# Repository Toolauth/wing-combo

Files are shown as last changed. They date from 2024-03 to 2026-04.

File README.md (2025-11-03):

# Combined Use Board
This is the **flagship board** for the [Toolauth](https://github.com/Toolauth) project.  More information about use, setup, and firmware is available in [this repo's wiki](https://github.com/Toolauth/wing-combo/wiki).

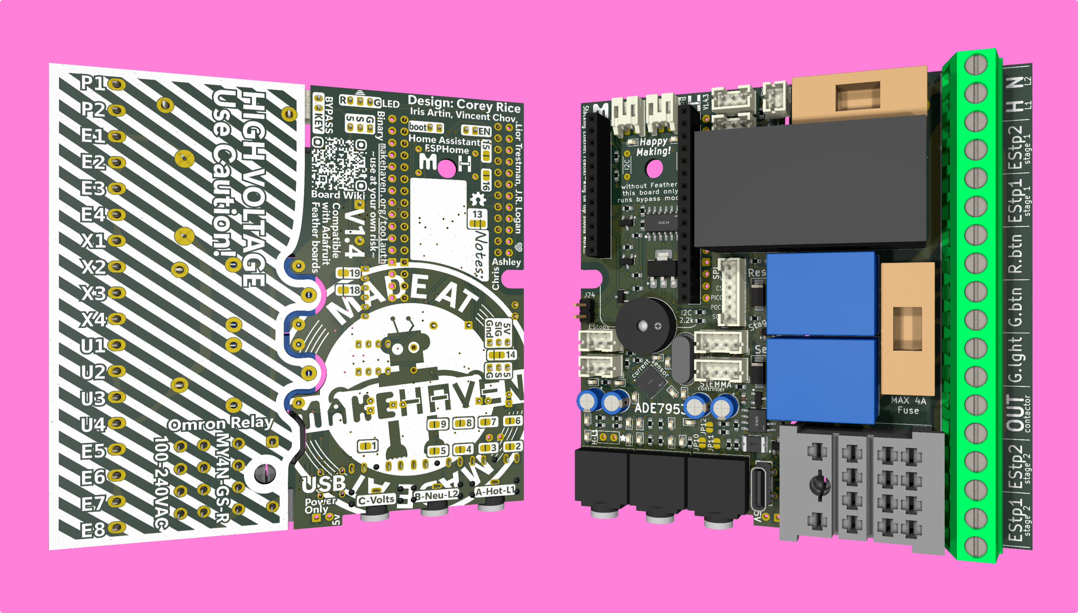
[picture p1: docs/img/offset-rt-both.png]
Combined use circuit board, front and back


It can allow for the management of power tools, and serve as the gateway for user authorization in a shared workshop.

The board has the following features:
* A stack of relays & a contactor for controlling power to the downstream tool.
* Its own power supply, to draw from the line supplying the downstream tool (_no extra power needed, if under 220VAC_).
* An ADE7953 current sensor, to monitor energy use/ status of the connected tool.
* Connectors to add in an RFID card reader (_workshop member's badges can swipe_).
* Connections for a hardware bypass, for quick-enabling of the tool.
* Simple connection for panel-mounted Red & Green status LEDs.
* 5V supply (from onboard transformer) in USB and solder-able form, for future expansion.

## How do I play with this PCB design?
It is as easy as downloading this design by whatever means you like: zip file, `clone`, etc. Then, open the `wing-combo.kicad_pro` file with any version of [KiCAD](https://www.kicad.org/) you like, but the newest version will probably be best.

## Adafuit Feather Specification
In avoidance of obsolescence, we have designed this board to the [Adafruit](https://www.adafruit.com/)'s [Feather Specification](https://learn.adafruit.com/adafruit-feather/feather-specification). The logic here is that the Feather specification itself should allow us to upgrade the 'brain' of this wing without needing a major re-design. 

_Yes, we could have designed a specific ESP32 into the board. But experience with previous generations has taught us that it is more convenient to make the boards with a MAC address removable._

## IOT Hosting
This project was designed to work with [Home Assistant](https://www.home-assistant.io/) and [ESPHome](https://esphome.io/), because they allow us to host the whole solution on-premises. However, this board is not tied to that stack by any means. There are lots of ways firmware and software could come together to make this work.

## Design Software
* Schematic and board designed in [KiCAD](https://www.kicad.org/).
* Graphics designed in [Inkscape](https://inkscape.org/).
* Ordered as assembled boards from [JLCPCB](https://jlcpcb.com/).

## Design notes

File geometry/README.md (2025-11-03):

# /geometry
All special geometry for this project is done in [Inkscape](https://inkscape.org/) and is derived from geometry exported from the board design in [KiCAD](https://www.kicad.org/). 

## file naming conventions
Files that end in `*.b141.svg` (or any board number) are primary Inkscape design files, and have carefully named layers, groups and drive all of the other designs.

Files that end in `*.multilayer.svg` all have multiple layers that represent the overlapping geometry of the board design. These files are useful for alignment and coordinating shapes with components on the board.

Files that end in `*.flattened.svg` are derived from their multilayer siblings, but have been reduced to just a single path that holds the information needed to import back into the KiCAD board design.

Files that end in `*.original_logo.svg` are primary-resource design files for the MakeHaven branding on the board.

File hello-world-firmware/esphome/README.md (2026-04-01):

# /esphome-hello-world
Here lives the simplest firmware examples, for use with ESPHome. 

They ought to connect all the standard/expected components, so that their state can be observed in [Home Assistant](https://www.home-assistant.io/) and [ESPHome](https://esphome.io/).

Here is the firmware that works.   
This was IRL tested with an [Adafruit Feather ESP32-S3 NoPSRAM](https://www.adafruit.com/product/5323) ([on platformio](https://docs.platformio.org/en/latest/boards/espressif32/adafruit_feather_esp32s3_nopsram.html))  

→ It appears the other [Feather Boards](https://learn.adafruit.com/adafruit-feather/feather-specification) have the same footprint, and all the “services” like `I2C` and `SPI` are in the same physical places. But the GPIO pin number can drift around from board to board: that is why this demo has GPIO you can commant/uncomment as needed. Also, to work in ESPHome, the board has to be supported by [Platformio](https://docs.platformio.org/en/latest/boards/)

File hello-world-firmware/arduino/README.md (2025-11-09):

# Example Arduino Firmware

> [!TIP]
> Arduino is not the firmware used by the [*Toolauth* project](https://github.com/Toolauth) creators.
> So, this firmware underwent less testing than the [ESPHome version](../esphome/). 
> Also, we recently had it 'touched up' by A.I. so you can use with caution....

This Arduino firmware is enough to show that all the hardware I/O is working for the board.

The Arduino IDE has opinions about libraries, so we have included a snapshot of all the needed ones and URLs to their origin. Open the folder, and have the Arduino IDE open the `io_test.ino` file to get this working on your board.

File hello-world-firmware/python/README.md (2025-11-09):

# Example Python Firmware

> [!CAUTION]
> We've never used this IO test - we just asked an A.I. to write it from the ESPHome version.

This Python firmware is enough to show that all the hardware I/O is working for the board.
You can get the microcontroller running as a webserver, and test that things work.

--> The tricky part will be finding the IP address of the board on your network...

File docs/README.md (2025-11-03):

# /docs
Here are all the basic documentation items:
* diagrams
* images
* layouts
* configurations

These items should help with setup

## Image Naming conventions
The images will all use a standard naming convention, so as to not break links on the wiki or Toolauth site. If you need to generate new images for a new design, be sure to use the same exact names. Also, the `map-locations.svg` file may be helpful.

- `docs\img\map\location-*.png` are images that show where specific parts are located on the board.
    - NOTE: in the `docs\img\map\` repo, there is an SVG file: `map-locations.svg` with many layers to generate the "location" images using [Inkscape](https://inkscape.org/). 
- `docs\img\map\sq-*.png` are the square(ish) images that serve as the foundation for all the location images, and generally take up less screen-area. Cropped down to size from "ortho" images using [Gimp](https://www.gimp.org/).
- `docs\img\map\ortho-*.png` are the orthographic perspective "base" images, from which all the square and location images are derived. Exported from [FreeCAD](https://www.freecad.org/) extension of [KiCAD](https://www.kicad.org/) (accessible from the `alt + 3` command).
- `docs\img\offset-*.png` are the "hero" images that use perspective (which blocks some viewing) and look the most realistic.

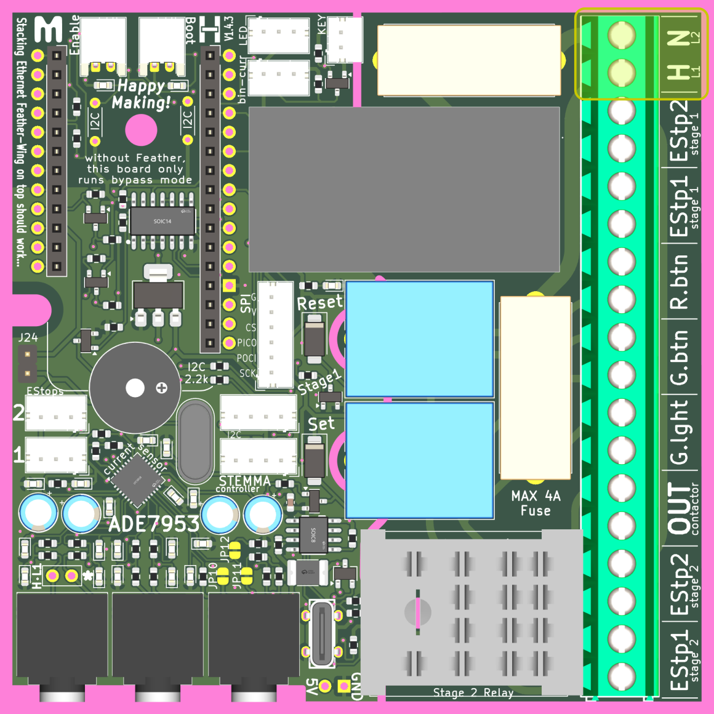
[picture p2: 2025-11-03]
docs/img/map/location-mains.png

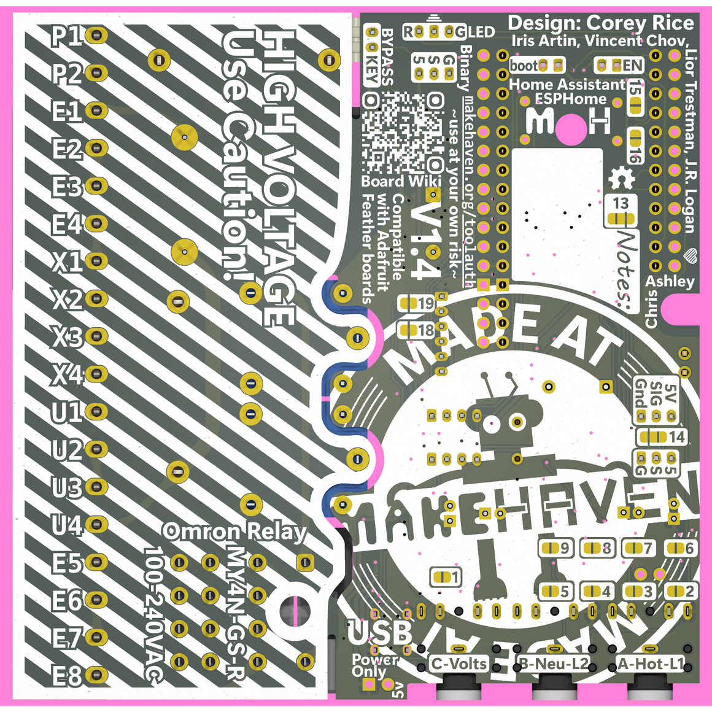
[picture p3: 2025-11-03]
docs/img/map/sq-ortho-back-rt.png

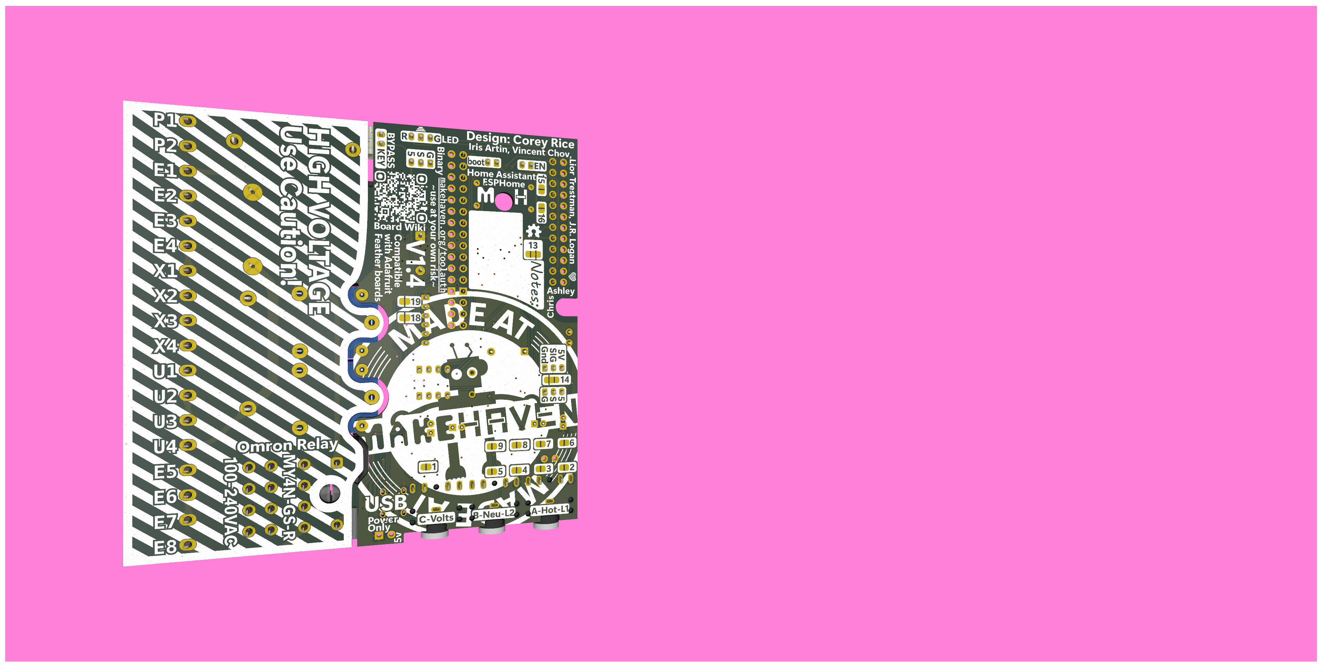
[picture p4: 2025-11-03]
docs/img/offset-rt-back.png

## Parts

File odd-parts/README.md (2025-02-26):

# /odd-parts
Here are all the components that are needed for the board design, but are not in the standard KiCAD library.

Include as much information as possible about these parts, so that they can be easily used, updated, researched, etc.

*****

The best tool to get this information is [JLC2KiCad_lib](https://github.com/TousstNicolas/JLC2KiCad_lib): a python script that gets all the files for a part from JLCPCB, and can store them here. 

example usage (make `some_accurate_name` a meaningful thing for this part):
```
JLC2KiCadLib C24112 -dir some_accurate_name                \
                    -model_dir some_accurate_name\model    \
                    -footprint_lib some_accurate_name      \
                    -symbol_lib_dir some_accurate_name\lib \
                    -symbol_lib some_accurate_name
```
Just need the part number as a positional argument. 

For our purposes, it is probably best if you stick to these conventions: each odd-part gets its own folder inside this one, and its own self-titled KiCad library.

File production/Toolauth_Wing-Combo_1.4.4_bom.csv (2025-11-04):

Designator | Footprint | Quantity | Value | LCSC Part #
BZ1 | BUZ-TH_BD12.0-P7.60-D0.6-FD | 1 | Buzzer | C96095
C1, C2, C24 | 0603 | 3 | 0.1uF | C14663
C10, C11, C12, C3, C4, C5, C6, C7, C8, C9 | 0603 | 10 | 33nF | C21117
C13, C16, C17, C22 | 0603 | 4 | 100nF | C14663
C14 | CP_Radial_D5.0mm_P2.00mm | 1 | 10uF | C88726
C15 | 0603 | 1 | 1uF | C15849
C18, C19, C23 | CP_Radial_D5.0mm_P2.00mm | 3 | 4.7uF | C88759
C20, C21 | 0603 | 2 | 20pF | C1648
D1 | 0603 | 1 | LED | C2286
D2, D3 | D_SMA | 2 | SS14 | C2480
F1 | Fuseholder_Cylinder-5x20mm_Stelvio-Kontek_PTF78_Horizontal_Open | 1 | Fuse | C717030
F2 | Fuseholder_Cylinder-5x20mm_Stelvio-Kontek_PTF78_Horizontal_Open | 1 | Fuse | C717030
F3 | 1812 | 1 | Polyfuse | C17313
J1 | PinSocket_1x12_P2.54mm_Vertical | 1 | Conn_01x12 | C2905419
J10 | JST_PH_B2B-PH-K_1x02_P2.00mm_Vertical | 1 | Conn_01x02_Female | C131337
J11, J12 | JST_PH_B4B-PH-K_1x04_P2.00mm_Vertical | 2 | Conn_01x04_Female | C131334
J13, J14, J15, J17 | JST_PH_B3B-PH-K_1x03_P2.00mm_Vertical | 4 | Conn_01x03_Female | C131339
J16 | JST_PH_B6B-PH-K_1x06_P2.00mm_Vertical | 1 | Conn_01x06_Female | C131342
J18, J19 | JST_PH_S2B-PH-K_1x02_P2.00mm_Horizontal | 2 | Conn_01x02_Female | C157932
J2 | PinSocket_1x16_P2.54mm_Vertical | 1 | Conn_01x16 | C2905421
J20, J21, J22 | CONN-TH_6P-P5.00_MX128-5.0-06P-GN01-CU-Y-A | 3 | Screw_Terminal_01x06 | C5290371
J24 | PinHeader_1x02_P2.54mm_Vertical | 1 | powered | C492401
J5, J6, J7 | Jack_3.5mm_CUI_SJ1-3525N_Horizontal | 3 |  | C692542
J8 | USB-C-TH_GT-USB-7055 | 1 | USB_C_Receptacle_USB2.0_16P | C2686963
JP1, JP15, JP16, JP2, JP3, JP4, JP5, JP6, JP7, JP8, JP9 | SolderJumper-2_P1.3mm_Open_RoundedPad1.0x1.5mm | 11 | no-filter-1
JP10, JP11, JP12, JP18, JP19 | SolderJumper-2_P1.3mm_Bridged_RoundedPad1.0x1.5mm | 5 | bridged
JP13, JP14 | SolderJumper-3_P1.3mm_Bridged12_RoundedPad1.0x1.5mm | 2 | SolderJumper_3_Bridged12
Q1 | TSOT-23 | 1 | PMOS | C15127
R1, R14, R15, R16, R17, R18, R20, R21, R26, R27, R29, R5, R6 | 0603 | 13 | 1k | C21190
R10, R11, R12, R9 | 0603 | 4 | 100 | C22775
R13, R19 | 0603 | 2 | 499k | C131054
R2, R22, R23, R24, R25, R28, R3, R30, R31, R36, R37, R38, R39, R4, R40 | 0603 | 15 | 10k | C25804
R34, R35 | 0603 | 2 | 56k | C23206
R7, R8 | 0603 | 2 | 2.2k | C4190
RELAY1, RELAY2 | Relay_SPDT_SANYOU_SRD_Series_Form_C | 2 | JQC-3FF/005-1ZS(551) | C9221
T1, T2, T3, T4, T5, T6 | SOT-23 | 6 | AO3400A | C427382
U1 | SOIC-14_L8.7-W3.9-P1.27-LS6.0-BL | 1 | 74HC02 | C350559
U2 | LFCSP-28-1EP_5x5mm_P0.5mm_EP3.14x3.14mm | 1 | ADE7953xCP | C515890
U3 | SOT-223-3_TabPin2 | 1 | AMS1117-3.3 | C6186
U4 | SOIC-8_L5.0-W4.0-P1.27-LS6.0-BL | 1 | LM393 | C7955
Y1 | Crystal_HC49-4H_Vertical | 1 | 3.58MHz | C2826865

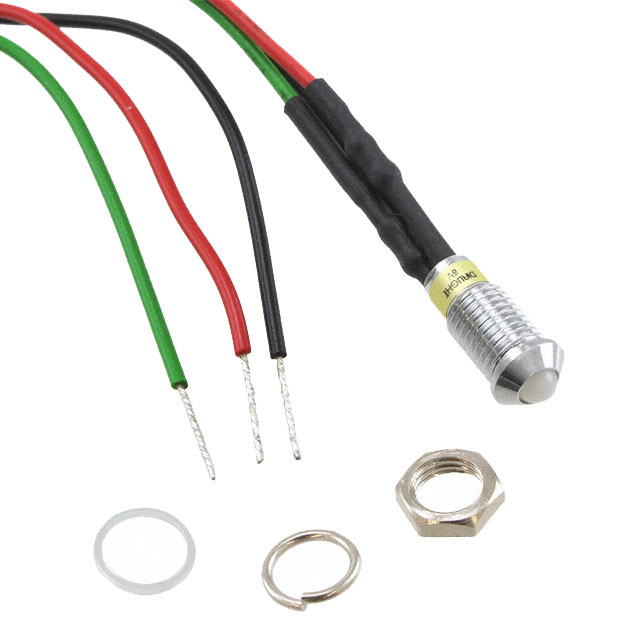
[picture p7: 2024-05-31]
docs/img/parts/led.jpg

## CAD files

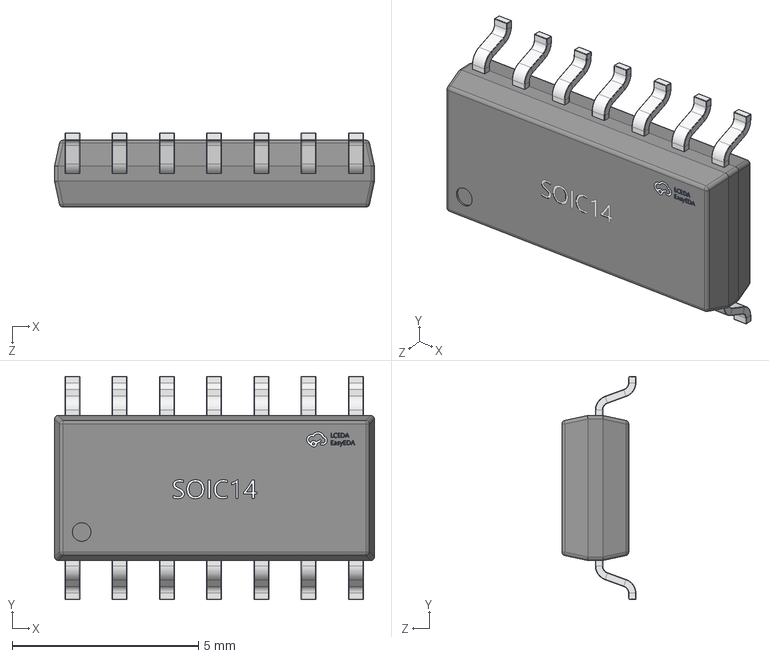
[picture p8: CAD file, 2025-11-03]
odd-parts/74hc02d/74hc02d_lib/model/SOIC-14_L8.7-W3.9-P1.27-LS6.0-BL.step
8.60 x 6.01 x 2.00 mm

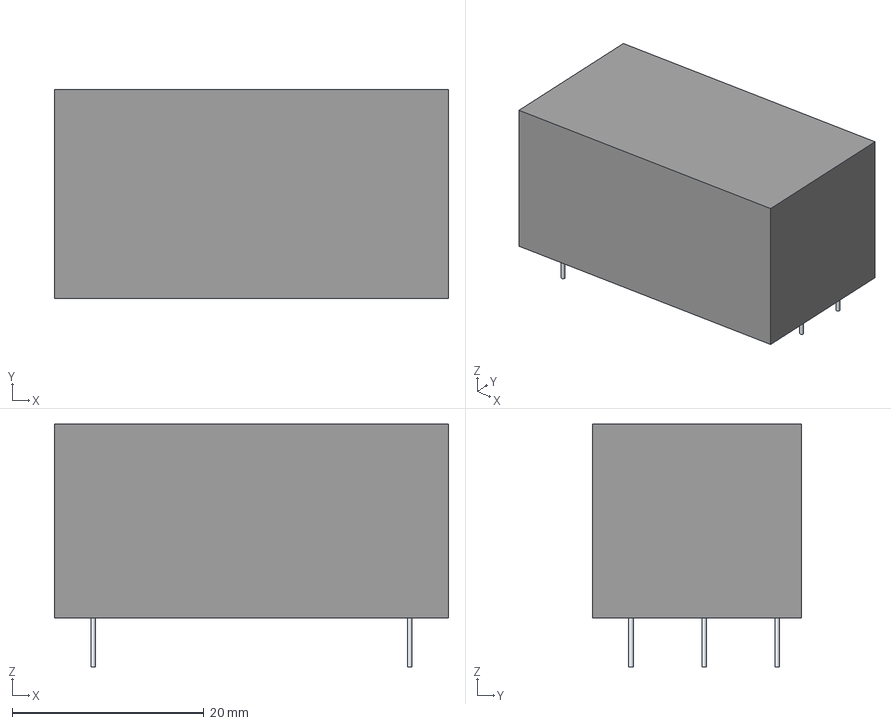
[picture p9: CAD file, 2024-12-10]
odd-parts/CFM06S050-E-Cincon/CFM06S050-E.stp
41.1 x 21.8 x 25.3 mm
Leads x 4

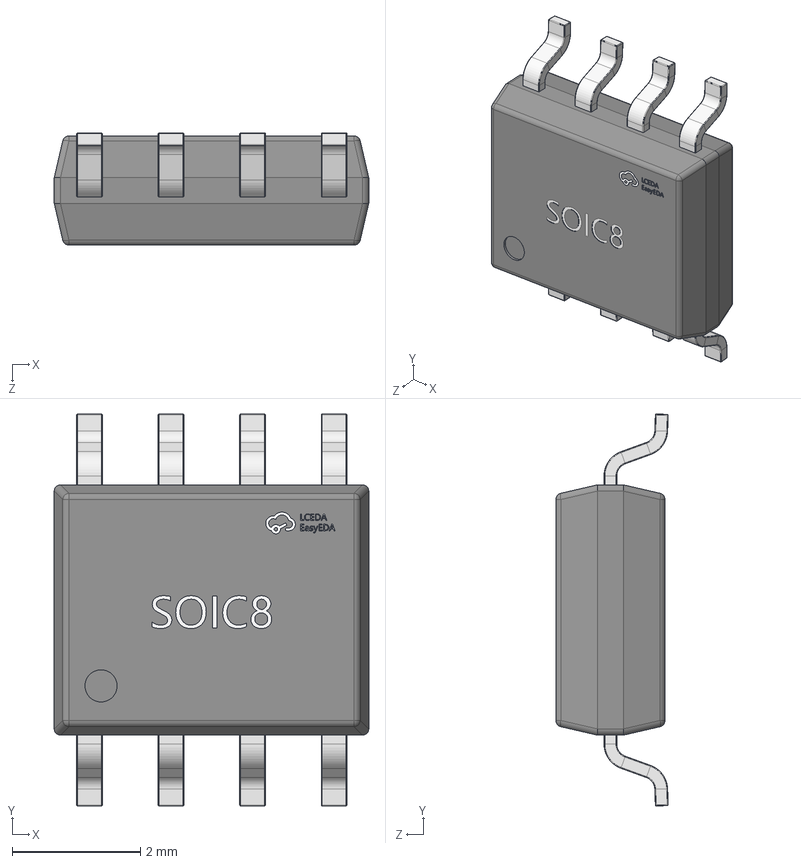
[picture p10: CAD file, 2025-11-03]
odd-parts/lm393/lm393/lm393model/SOIC-8_L5.0-W4.0-P1.27-LS6.0-BL.step
4.90 x 6.11 x 1.75 mm

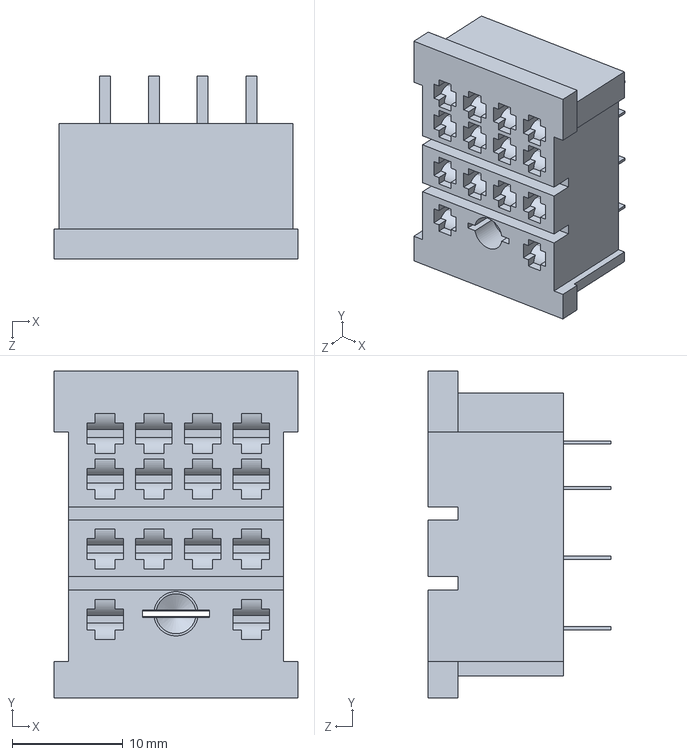
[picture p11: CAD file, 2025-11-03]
odd-parts/mk_relay_socket/PY14_02.step
22.0 x 29.5 x 16.5 mm

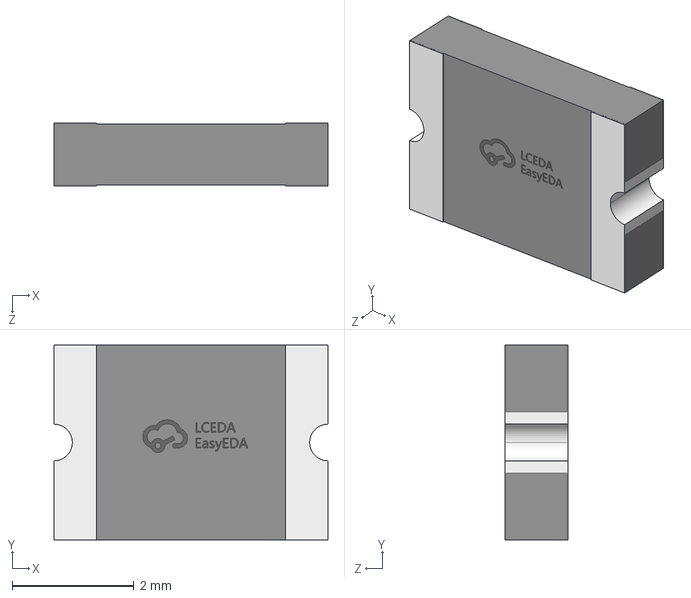
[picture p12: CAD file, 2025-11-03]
odd-parts/PPTC_fuse/PPTC_fuse/PPTC_fusemodel/F1812.step
4.50 x 3.20 x 1.04 mm

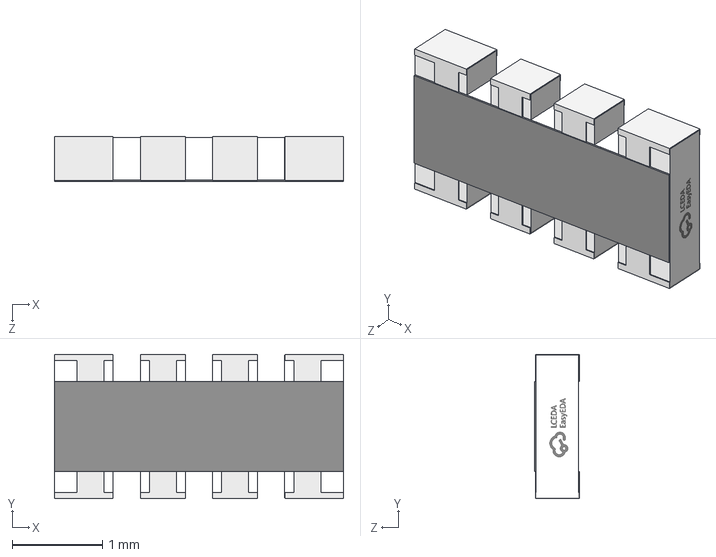
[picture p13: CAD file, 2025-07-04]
odd-parts/resistor_arrays/resistor_arrays/model/RES-ARRAY-SMD_0603-8P-L3.2-W1.6-BL.step
3.20 x 1.60 x 0.5 mm

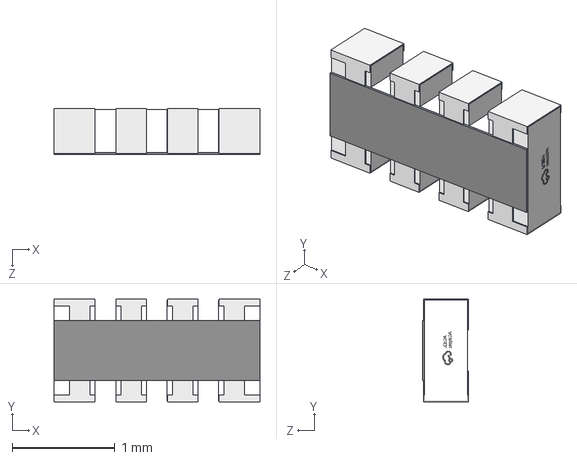
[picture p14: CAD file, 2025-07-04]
odd-parts/resistor_arrays/resistor_arrays/model/RES-ARRAY-SMD_0402-8P-L2.0-W1.0-BL.step
2.00 x 1.00 x 0.45 mm

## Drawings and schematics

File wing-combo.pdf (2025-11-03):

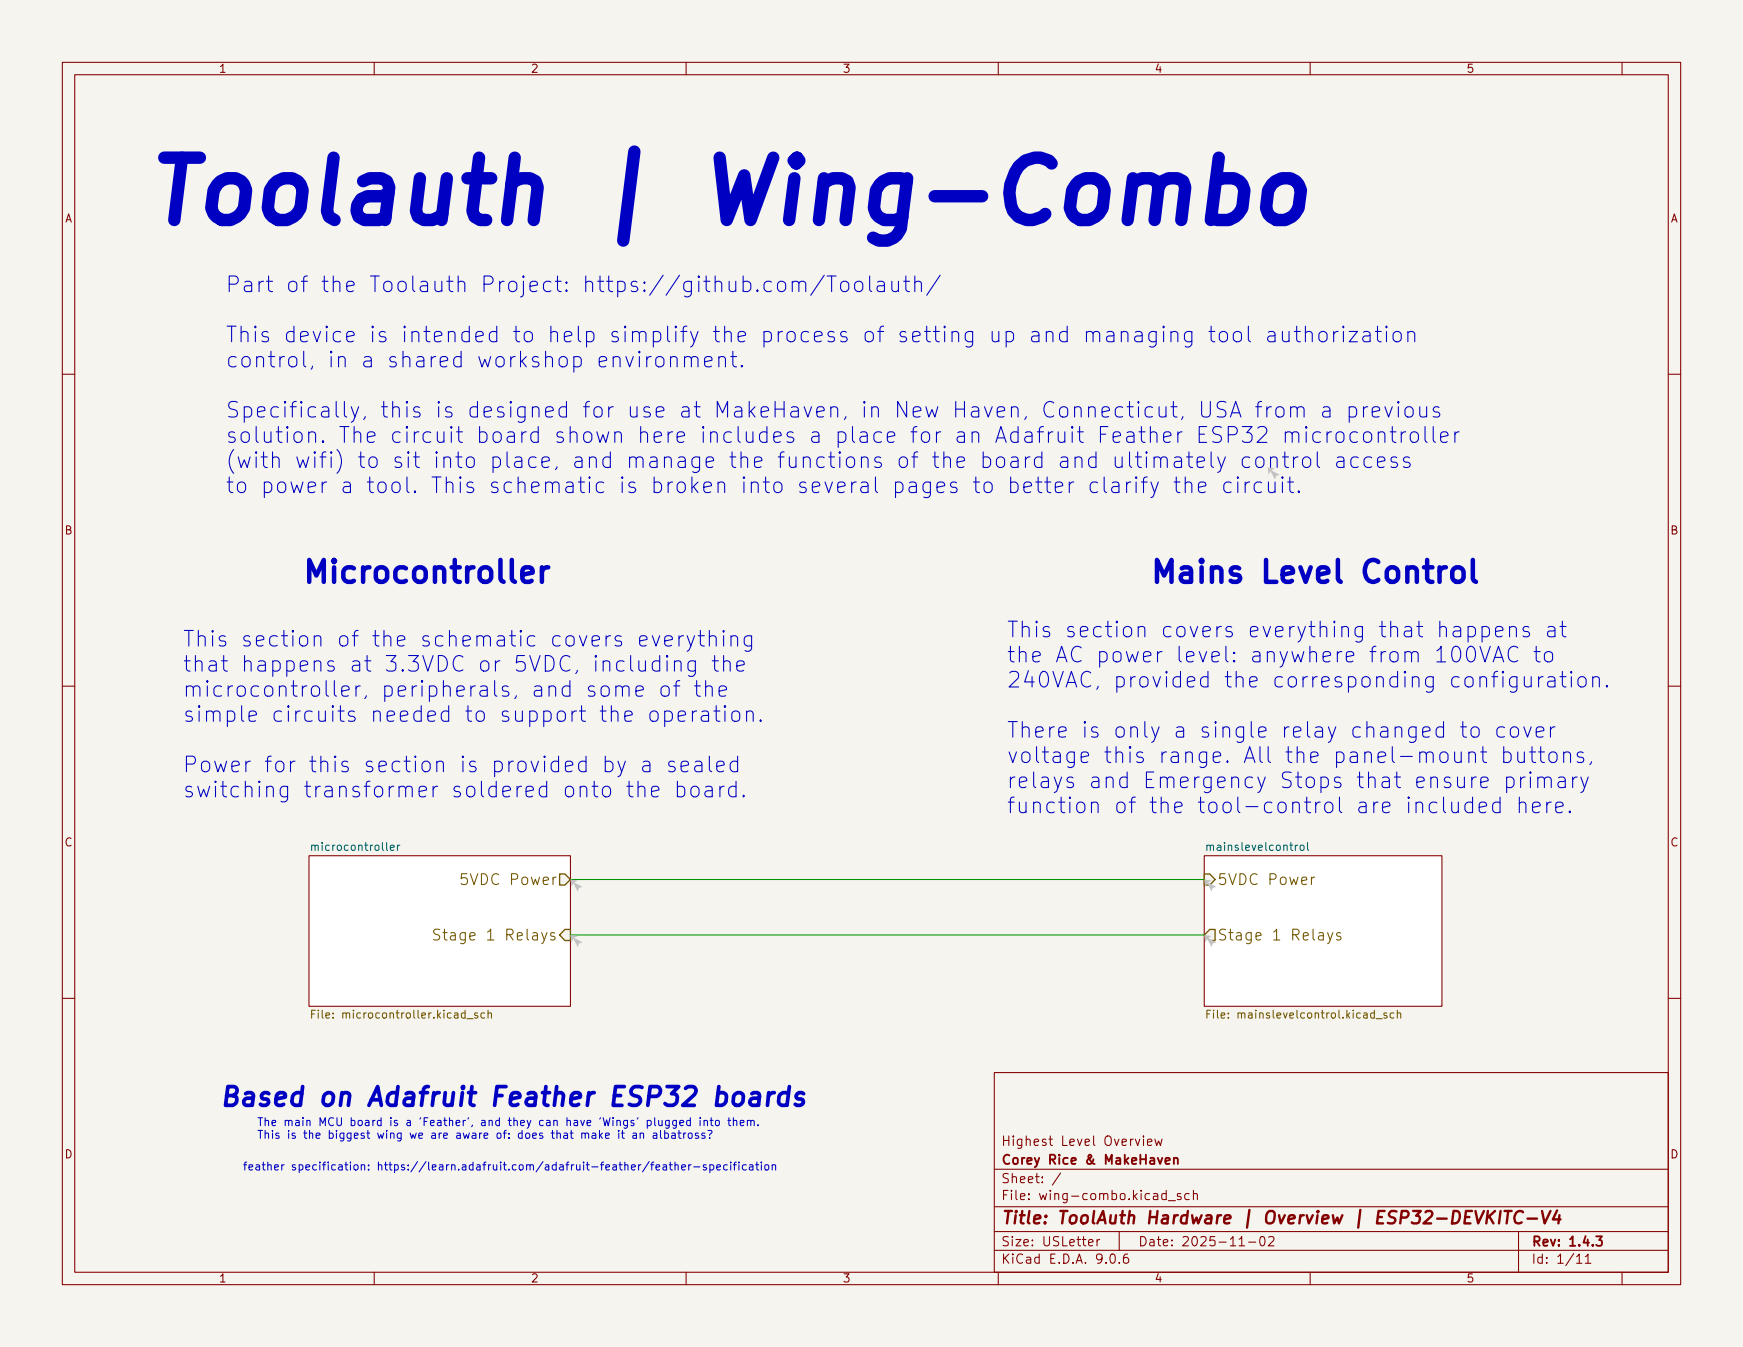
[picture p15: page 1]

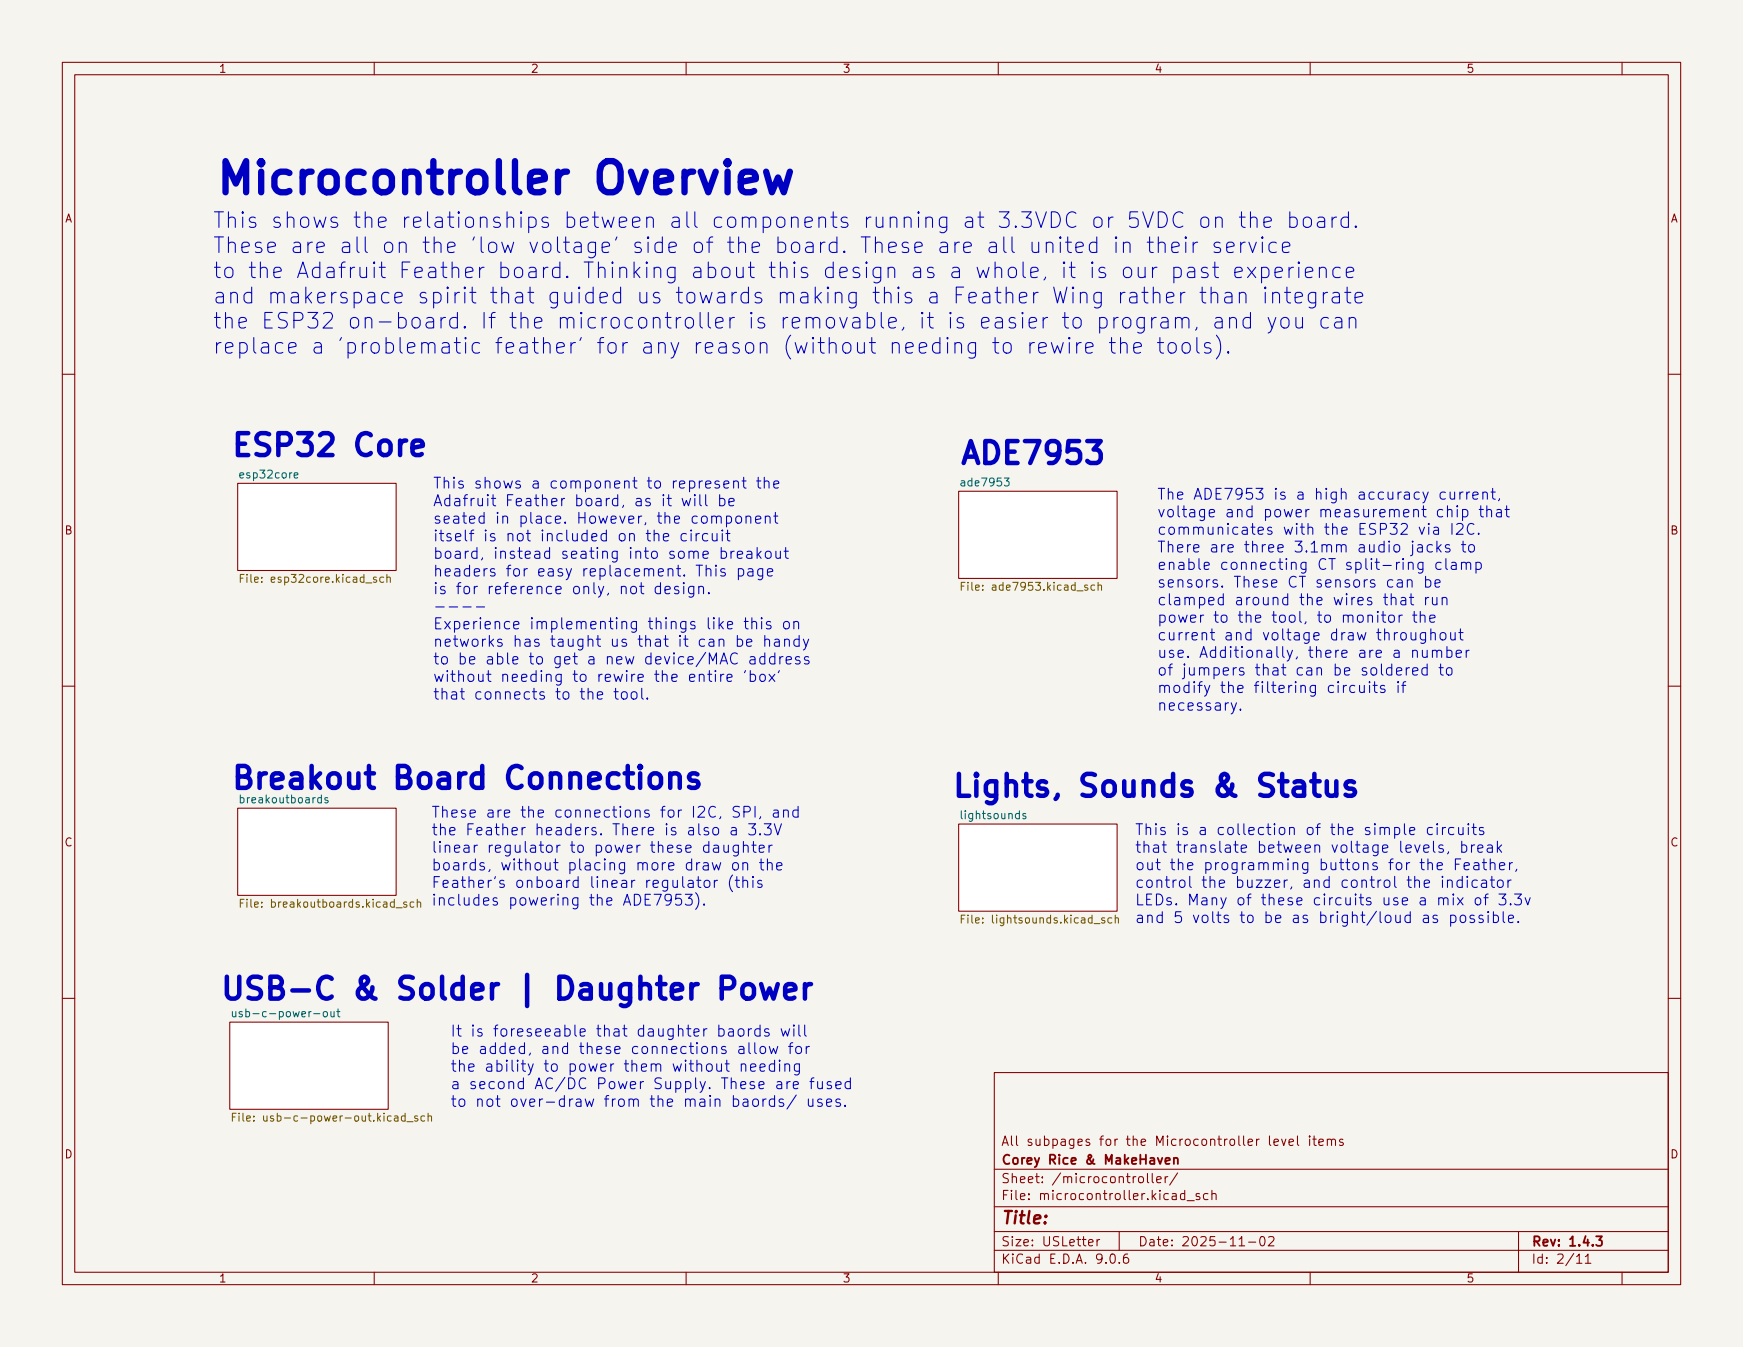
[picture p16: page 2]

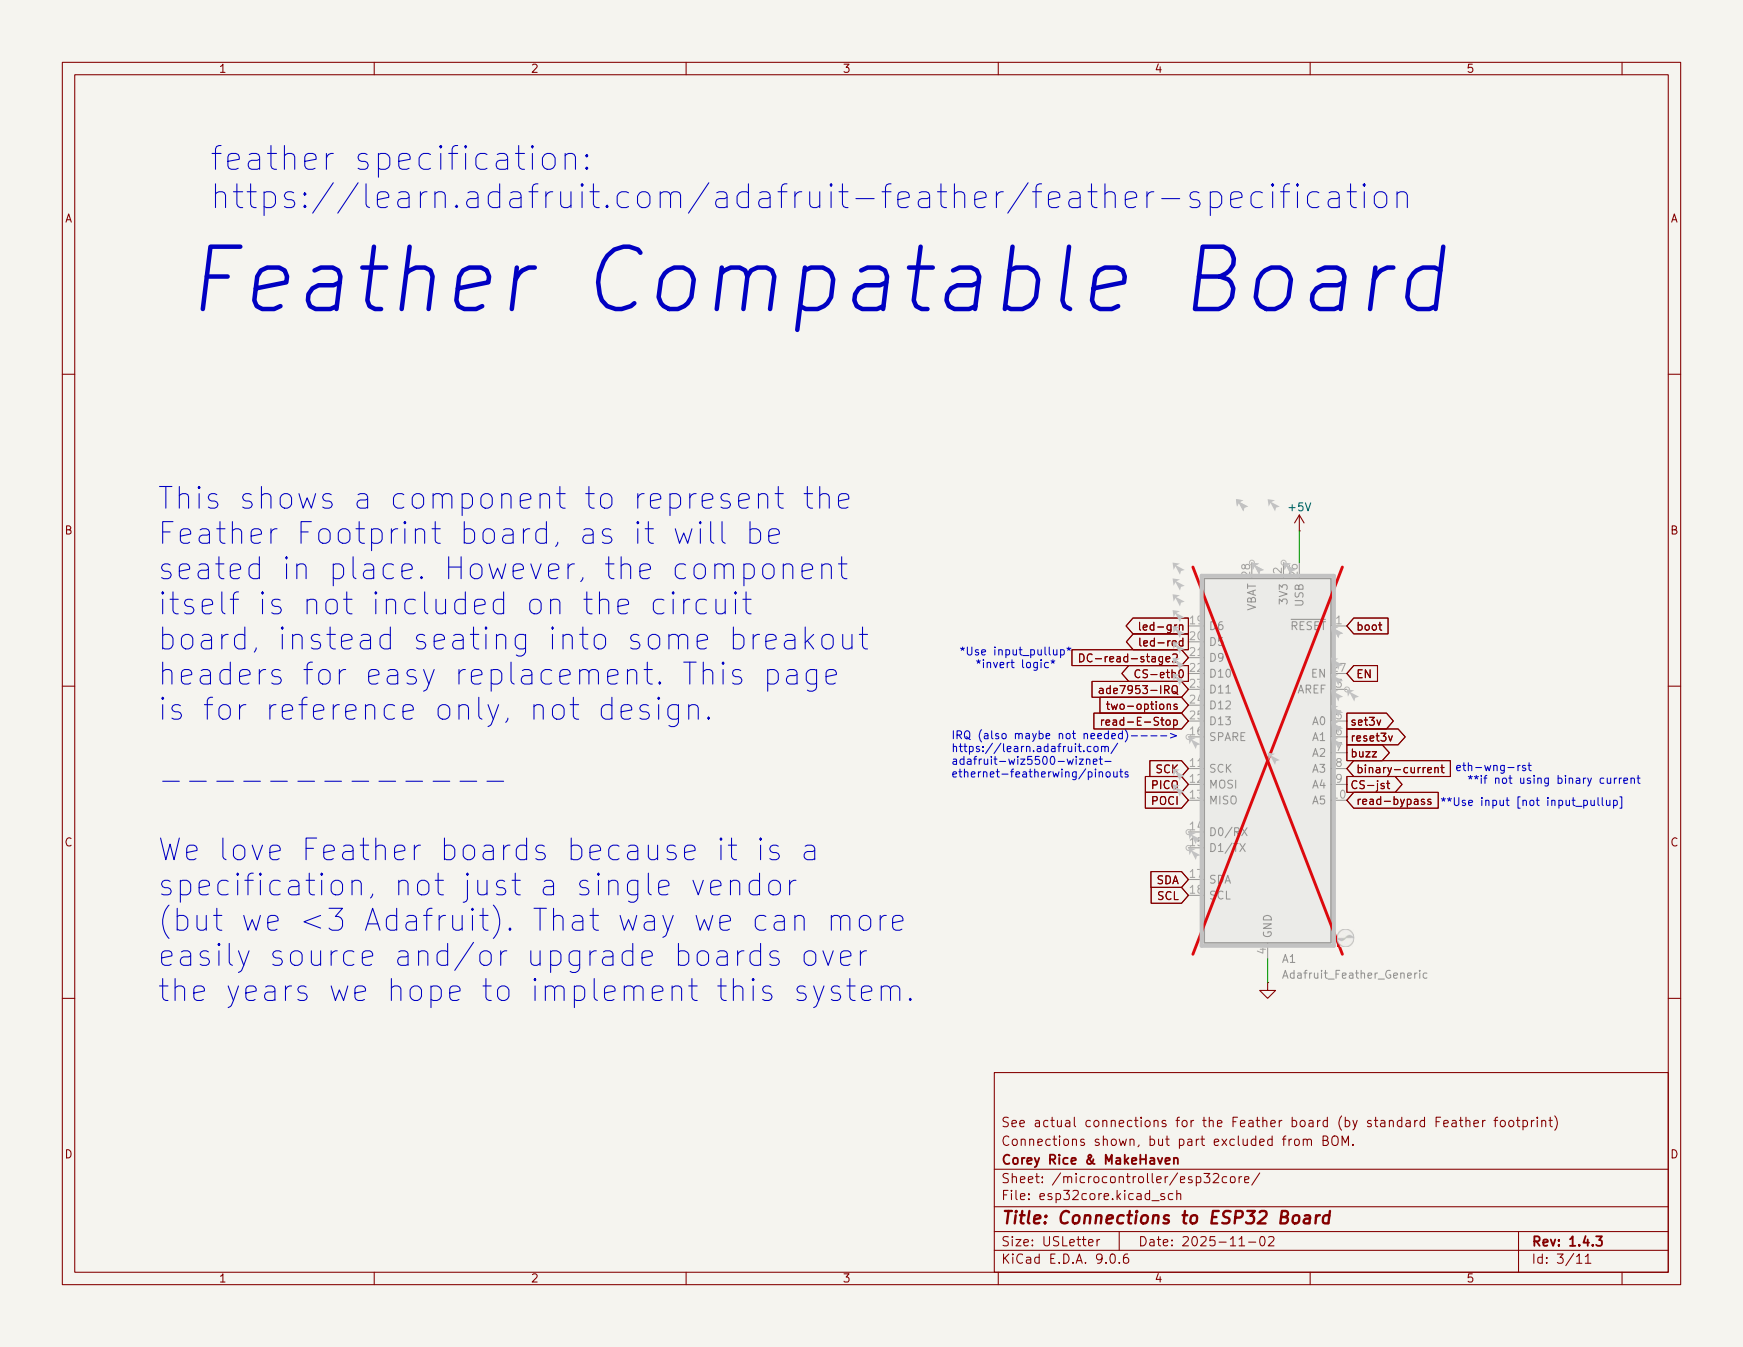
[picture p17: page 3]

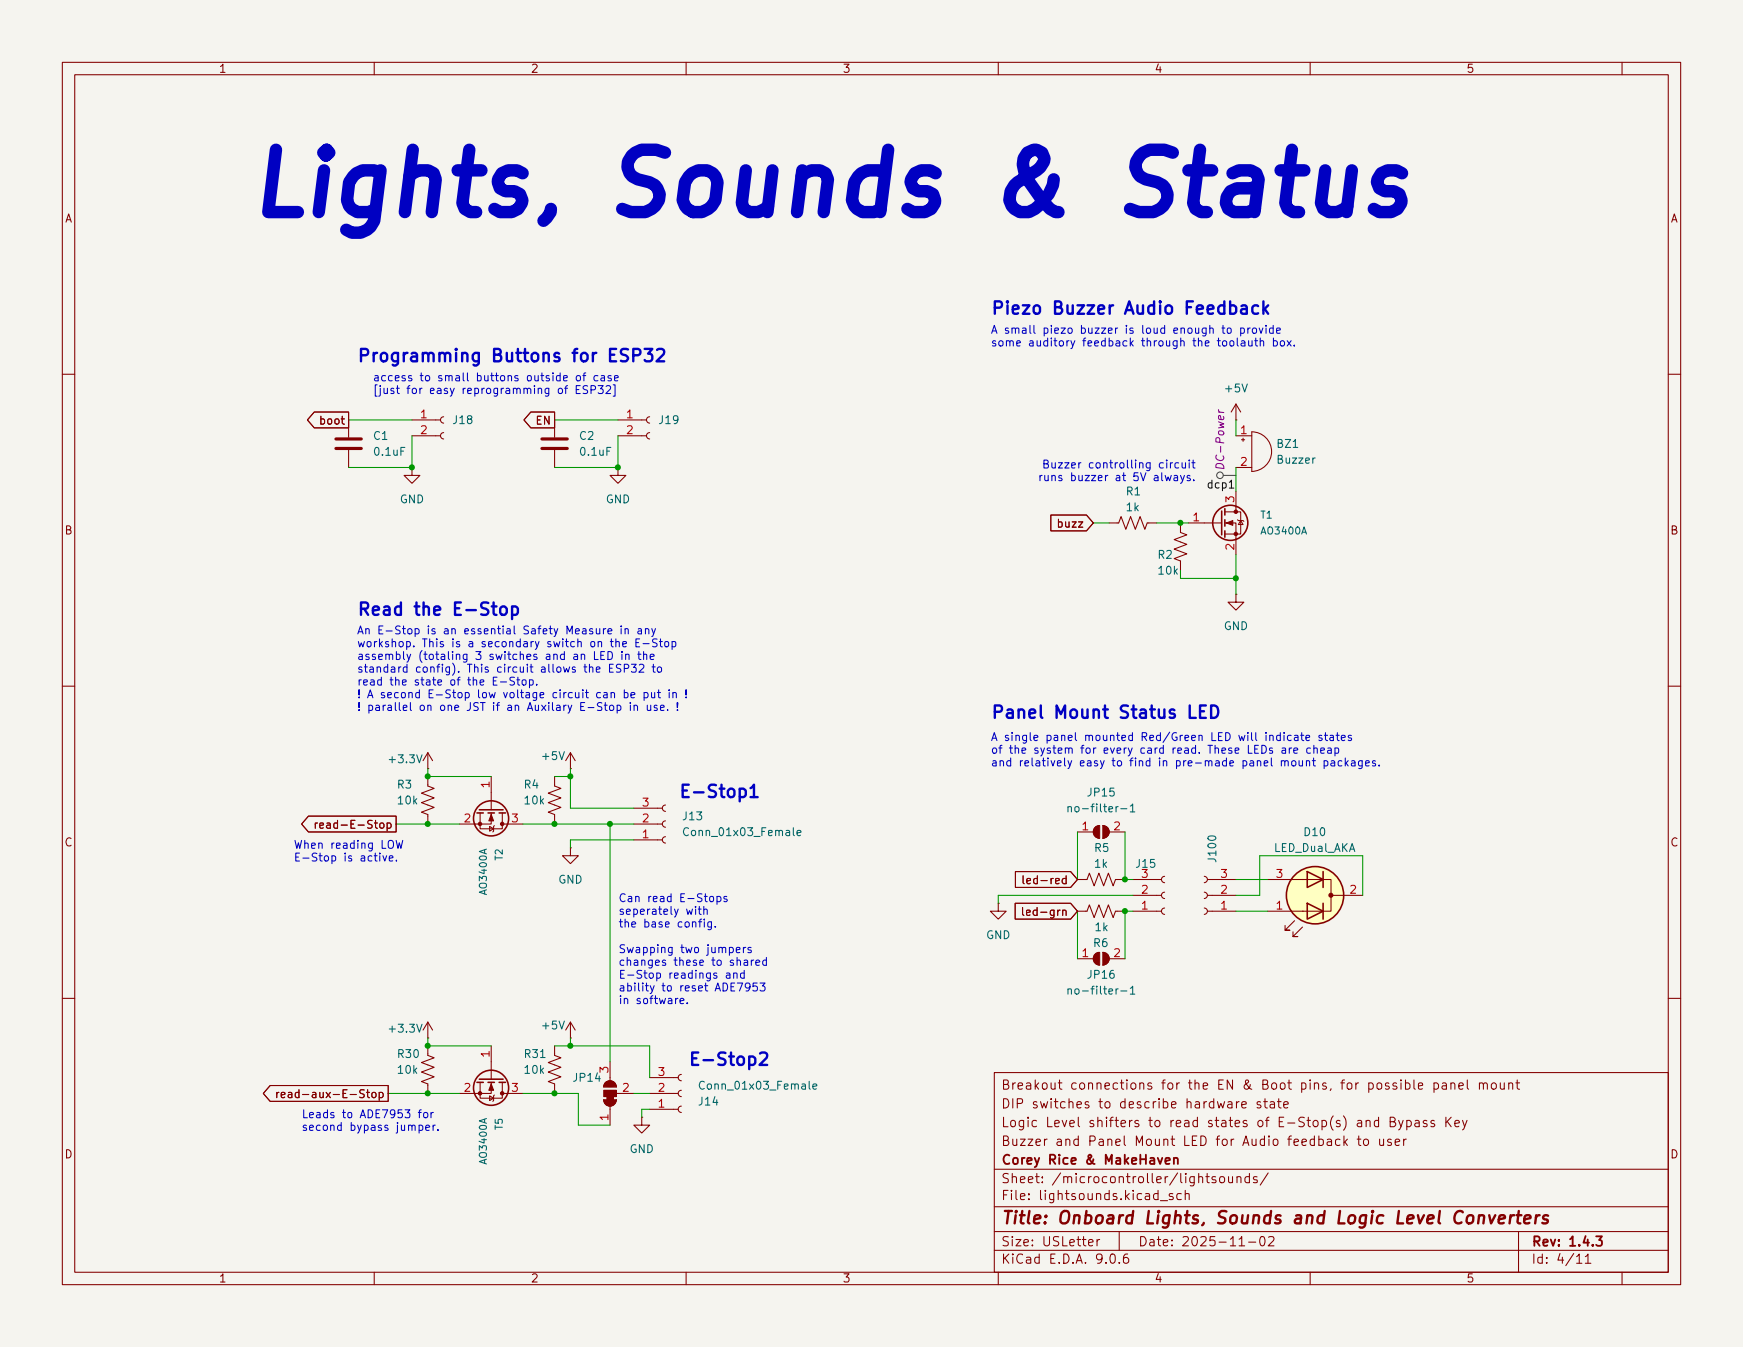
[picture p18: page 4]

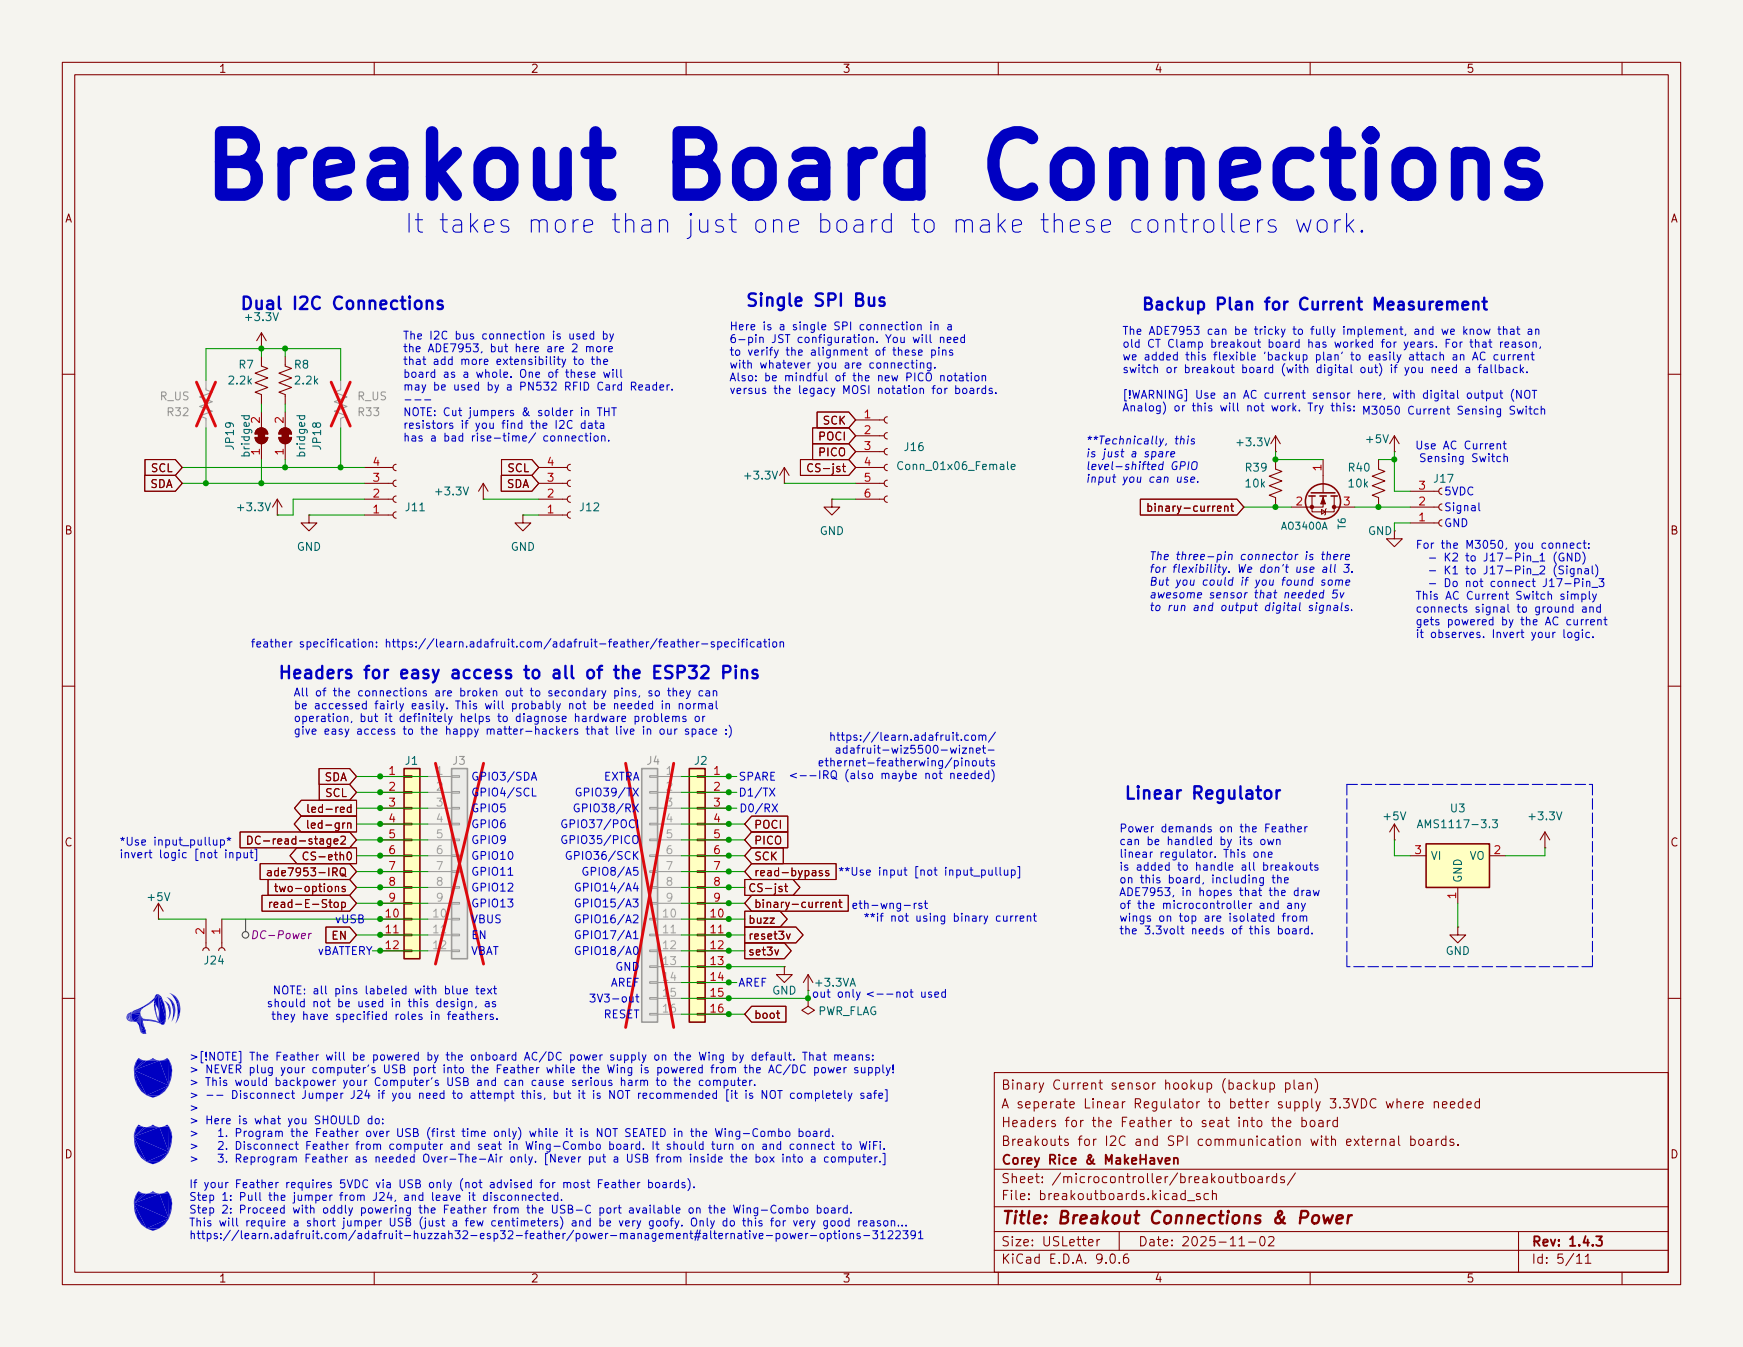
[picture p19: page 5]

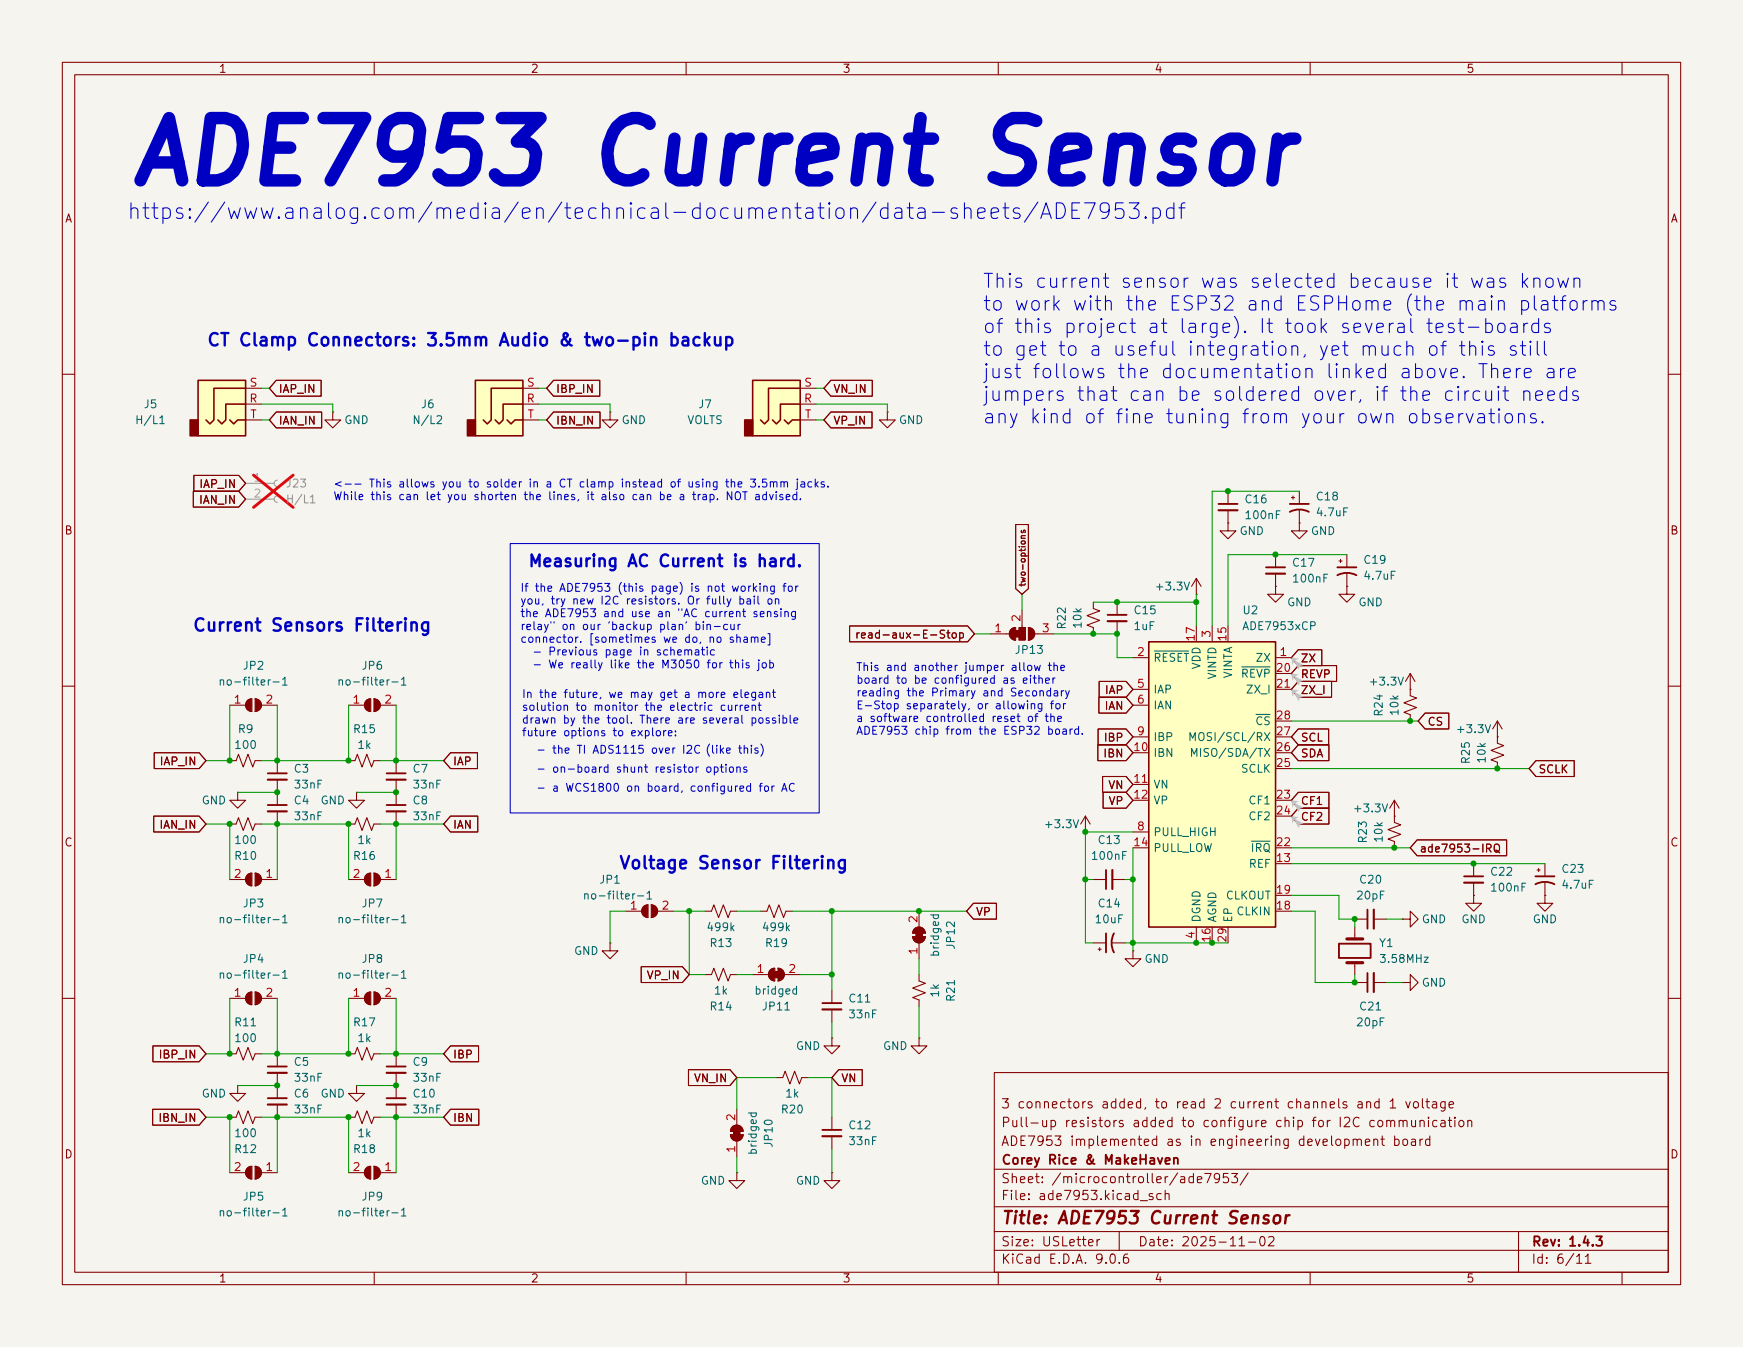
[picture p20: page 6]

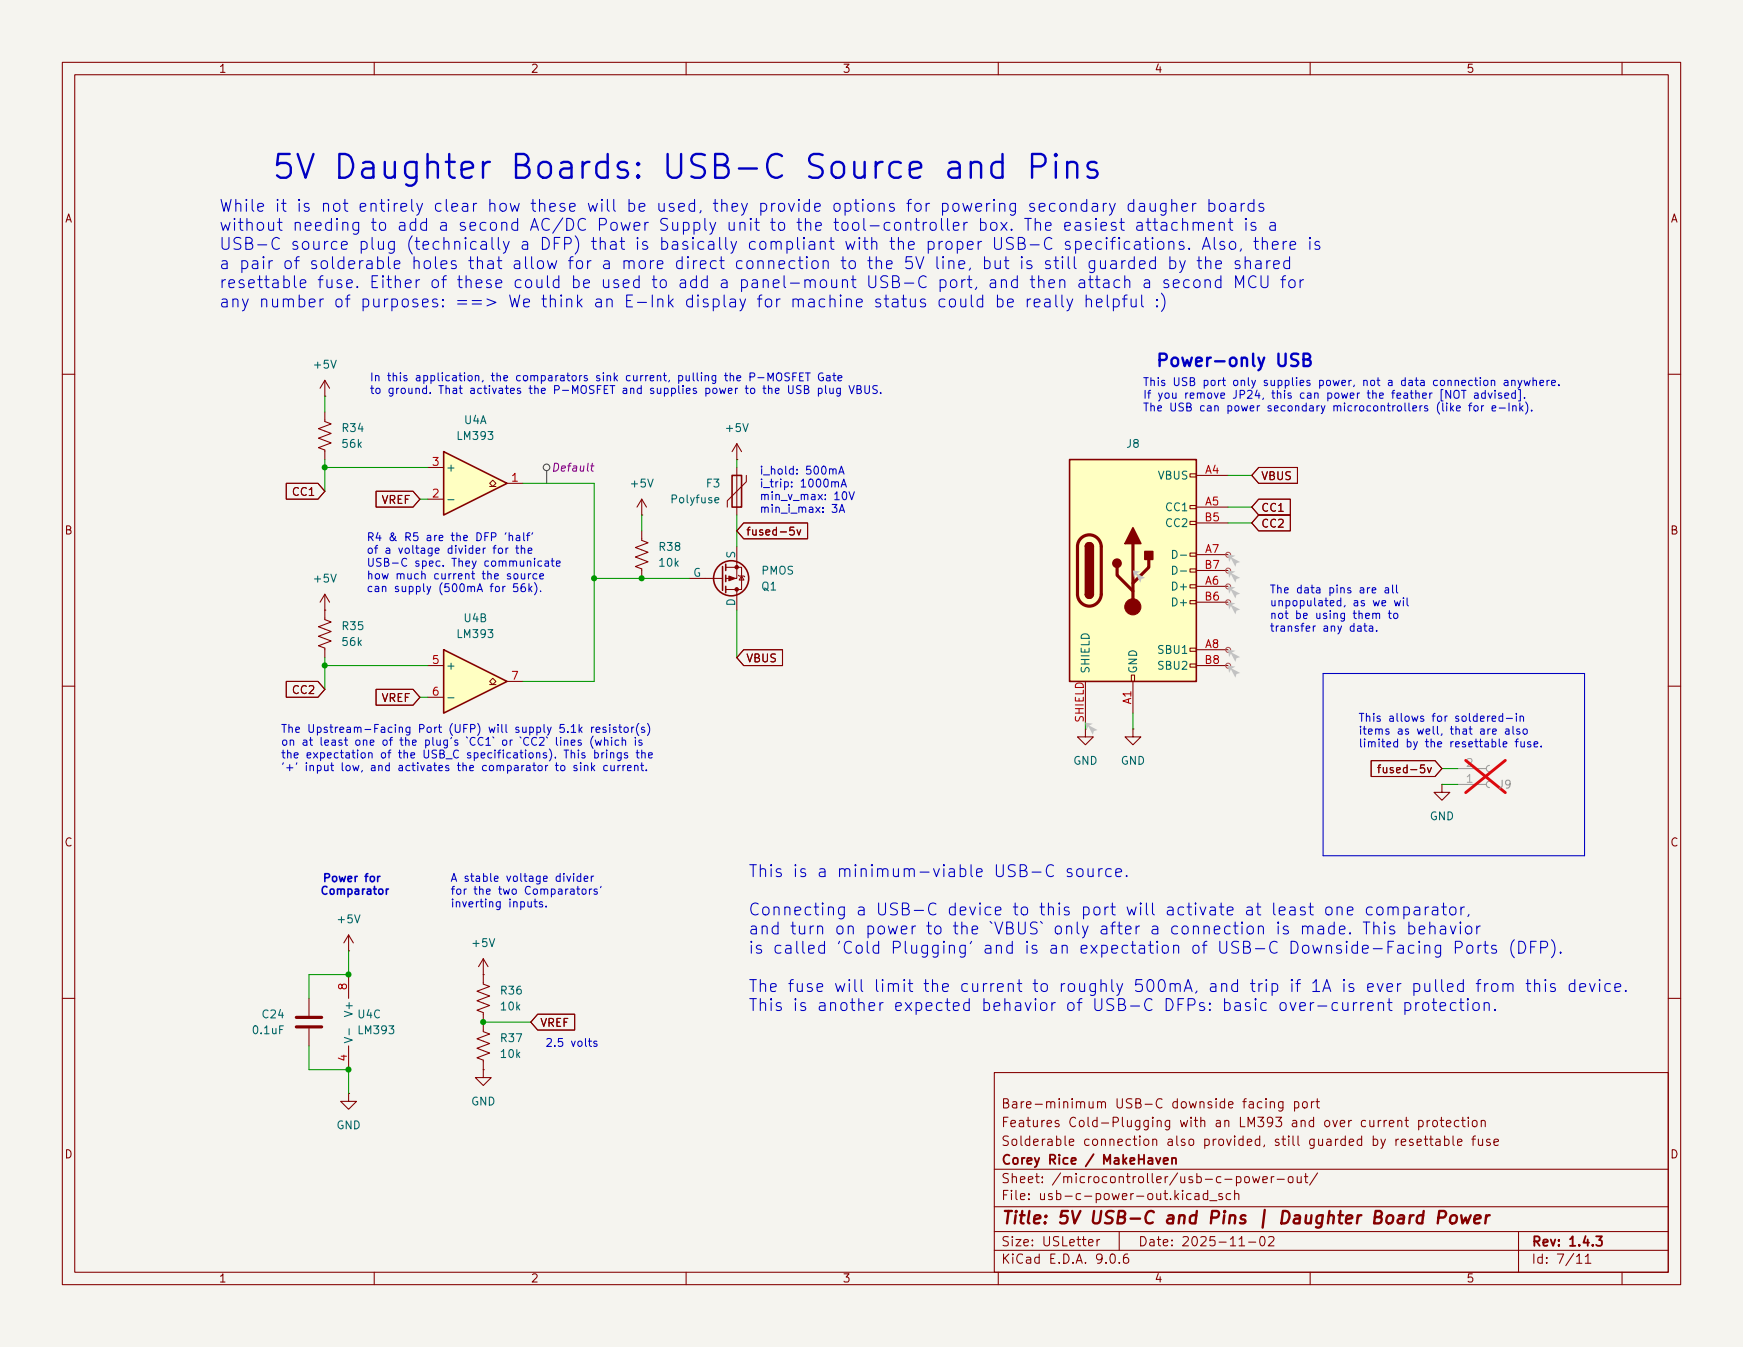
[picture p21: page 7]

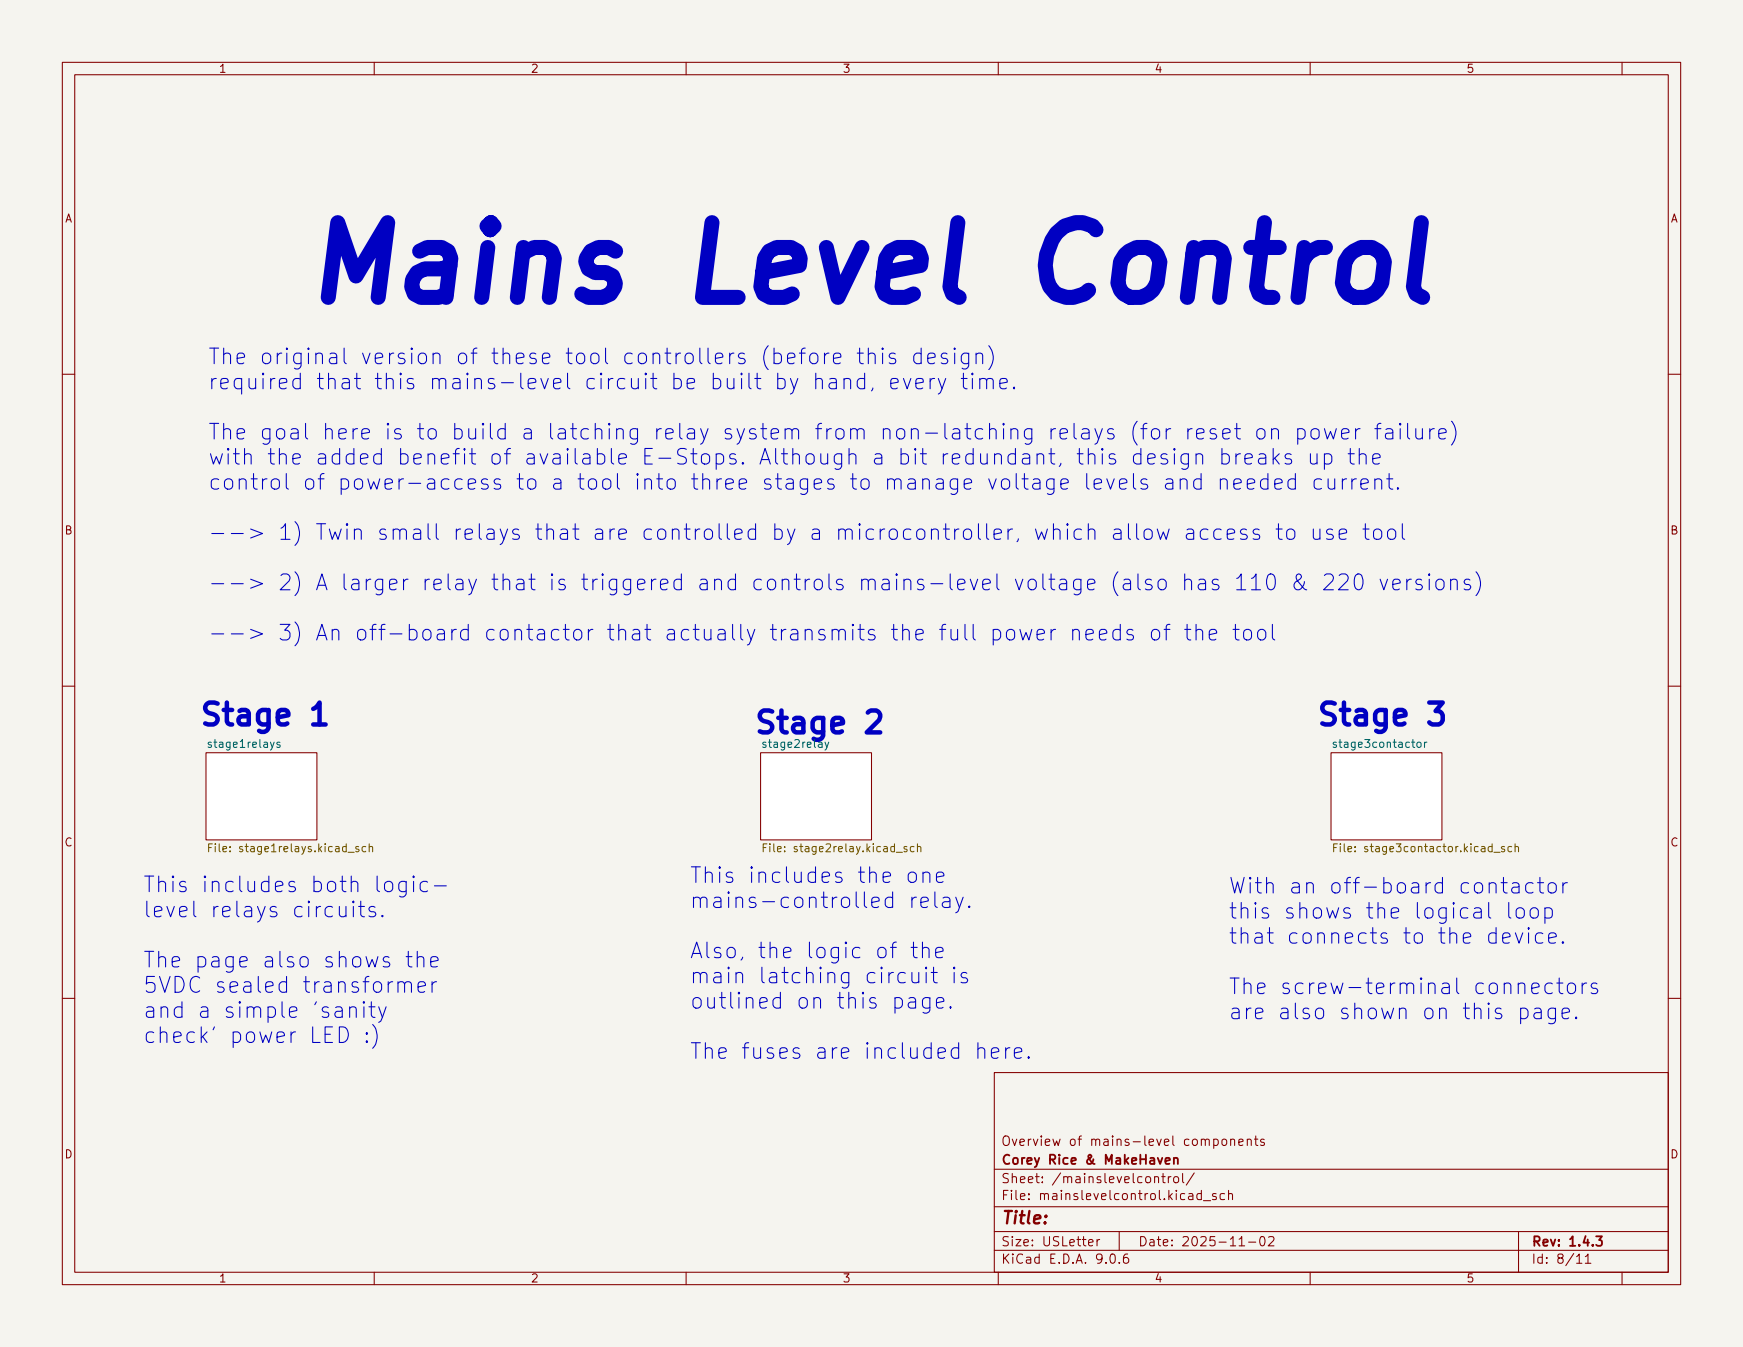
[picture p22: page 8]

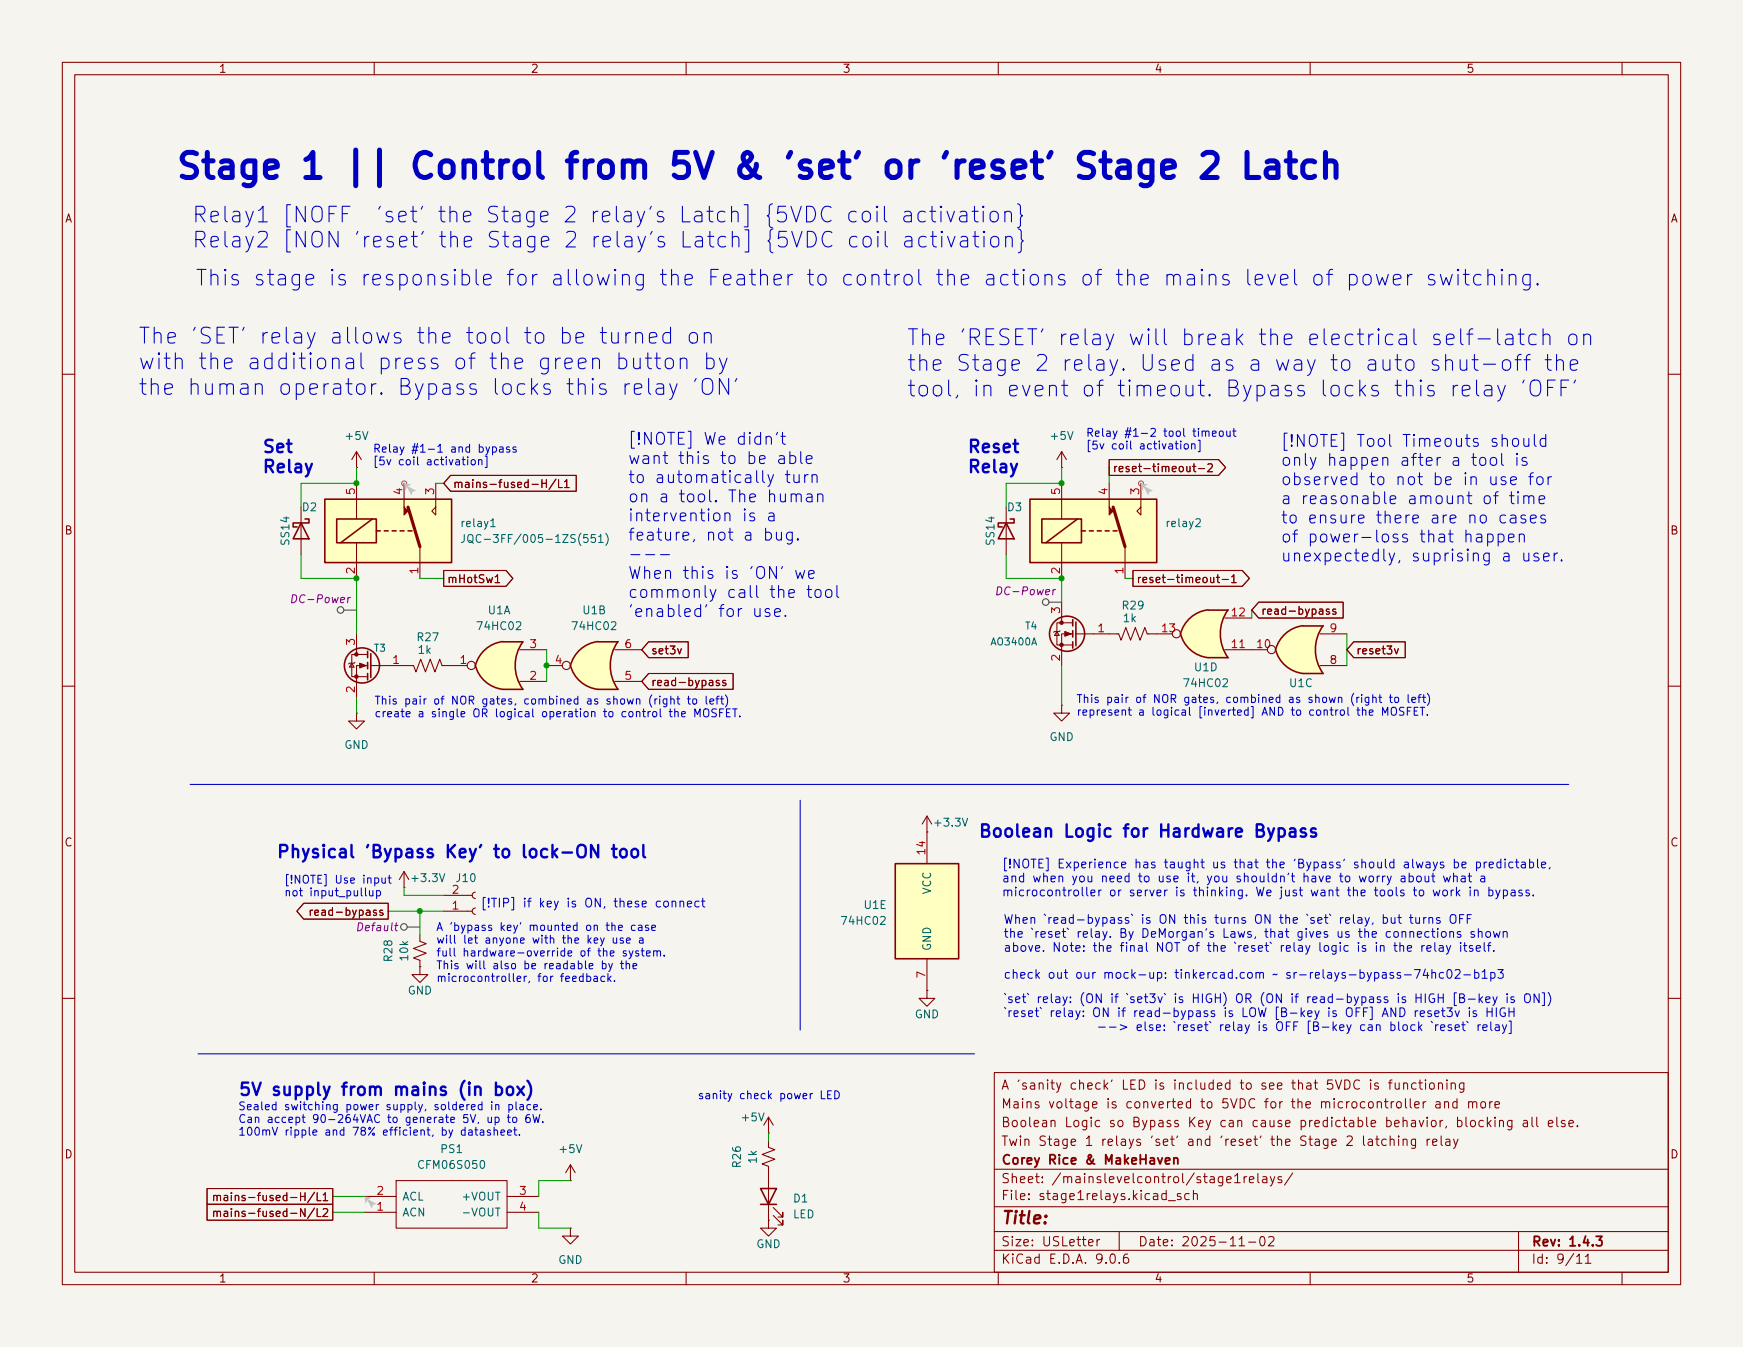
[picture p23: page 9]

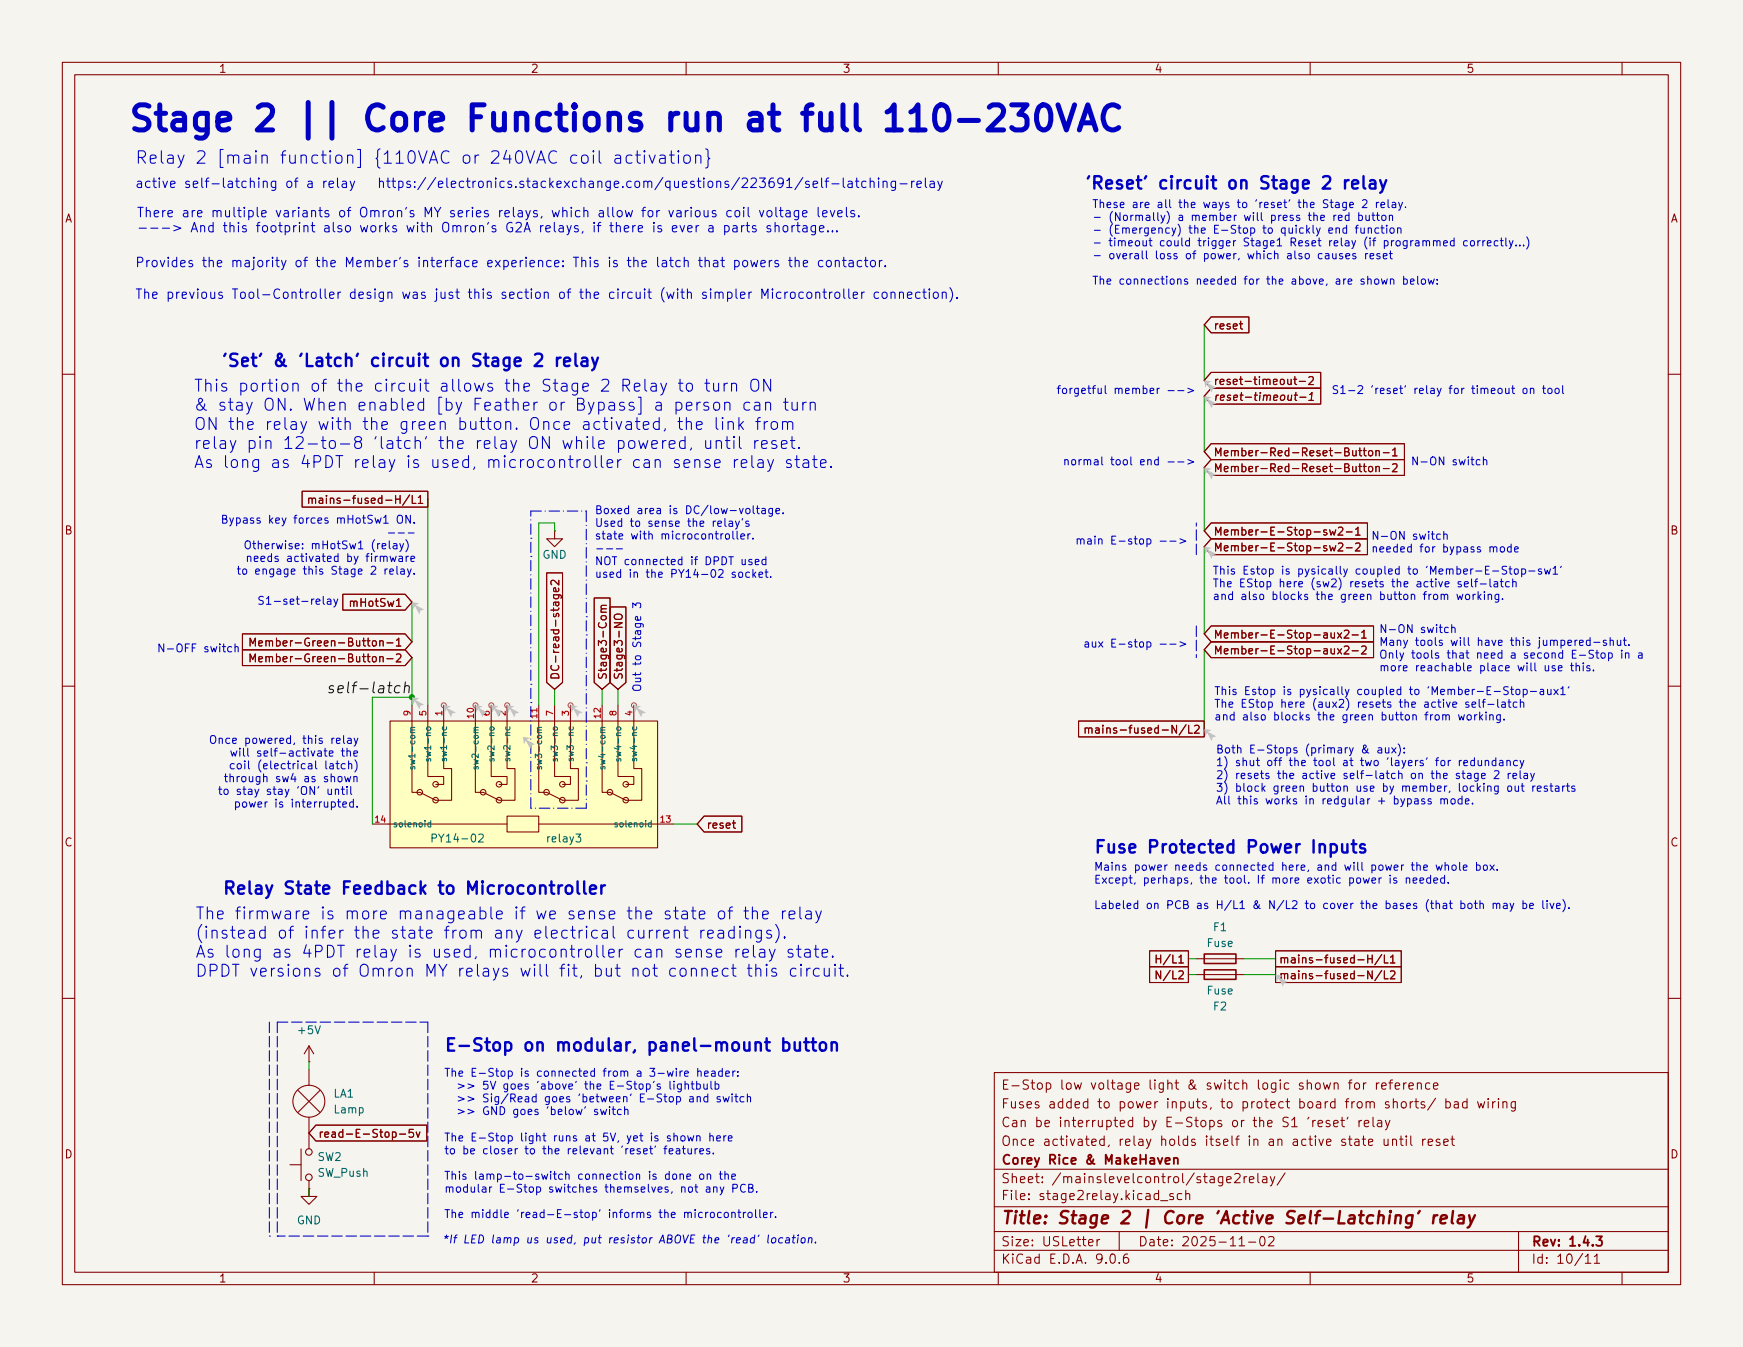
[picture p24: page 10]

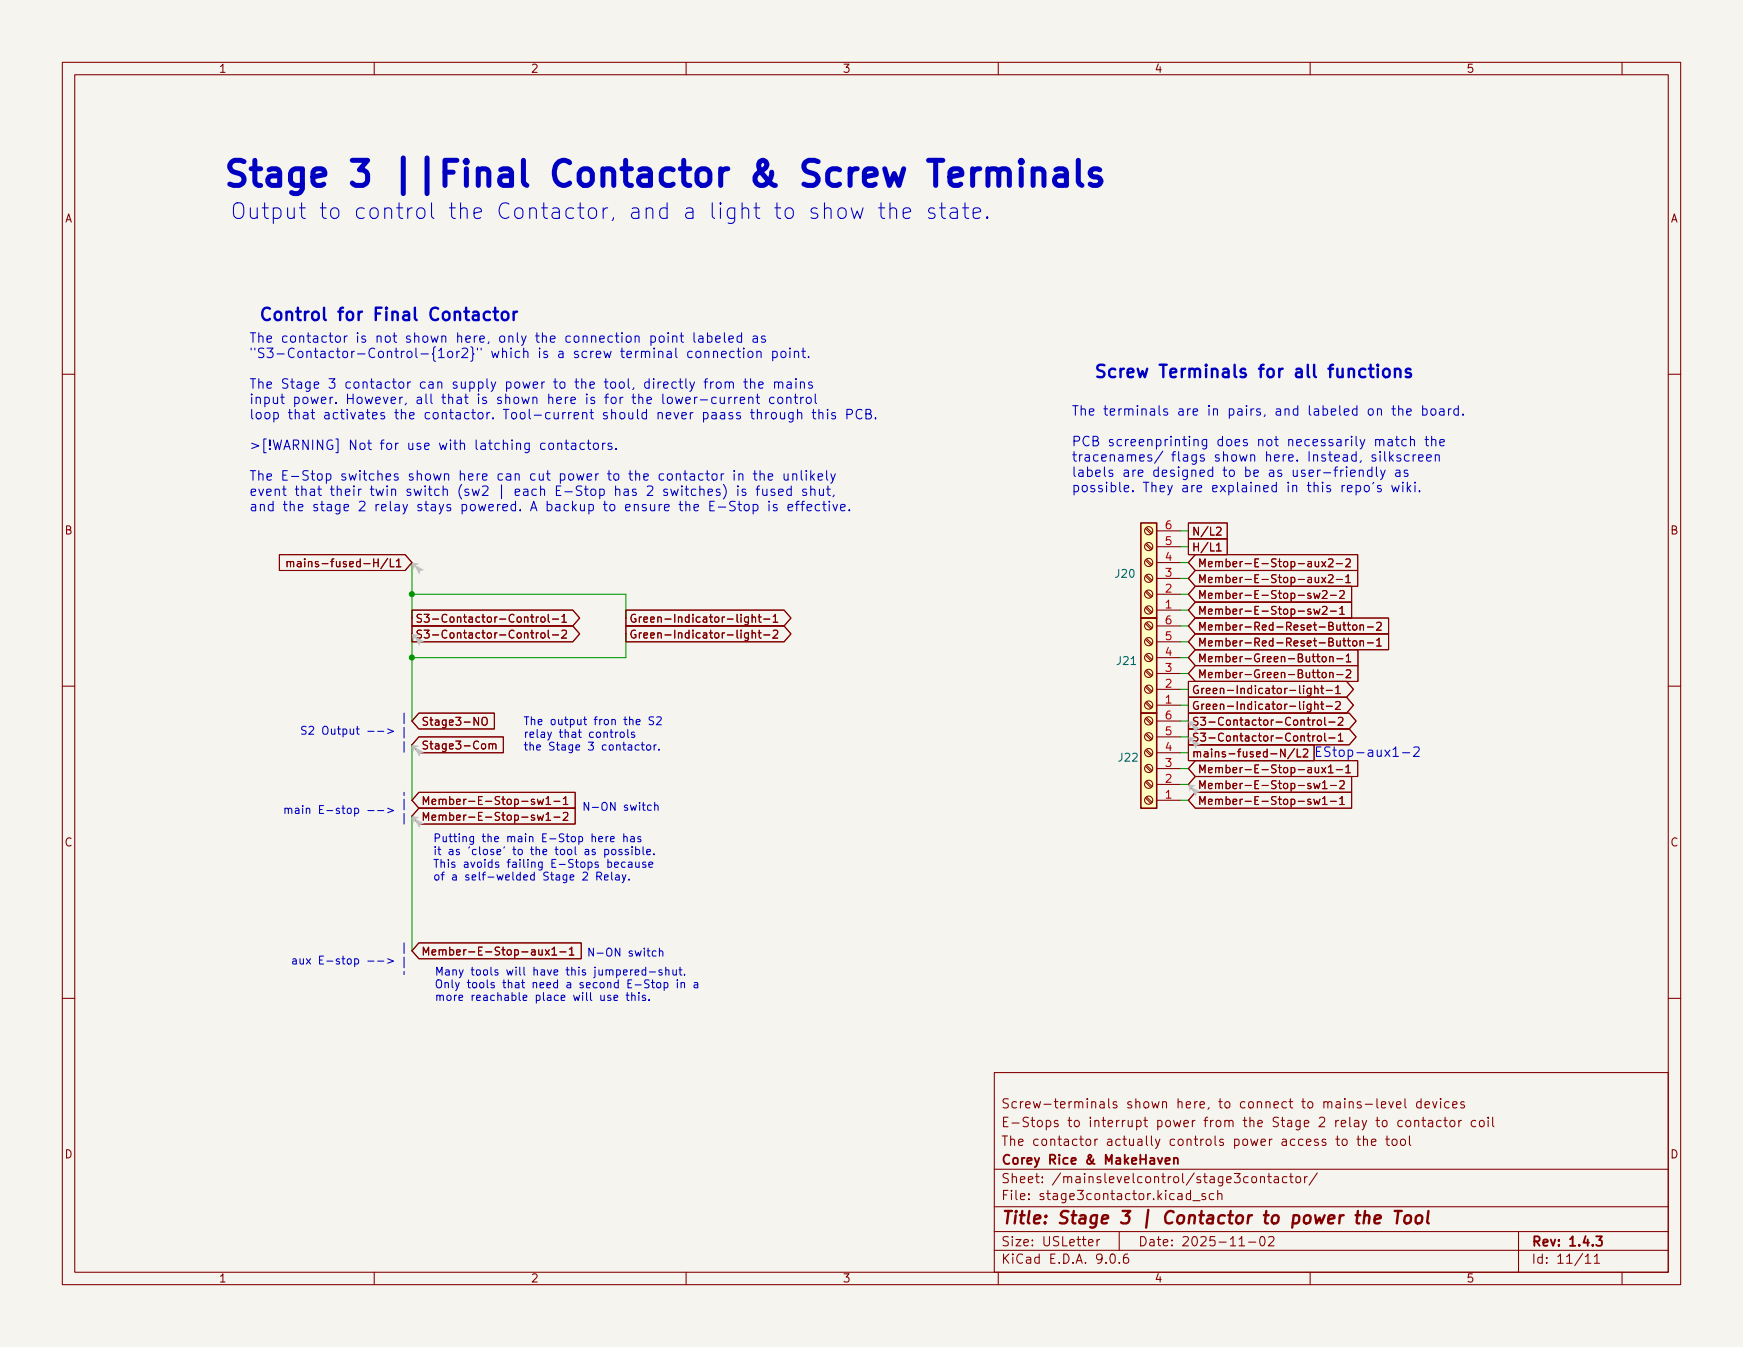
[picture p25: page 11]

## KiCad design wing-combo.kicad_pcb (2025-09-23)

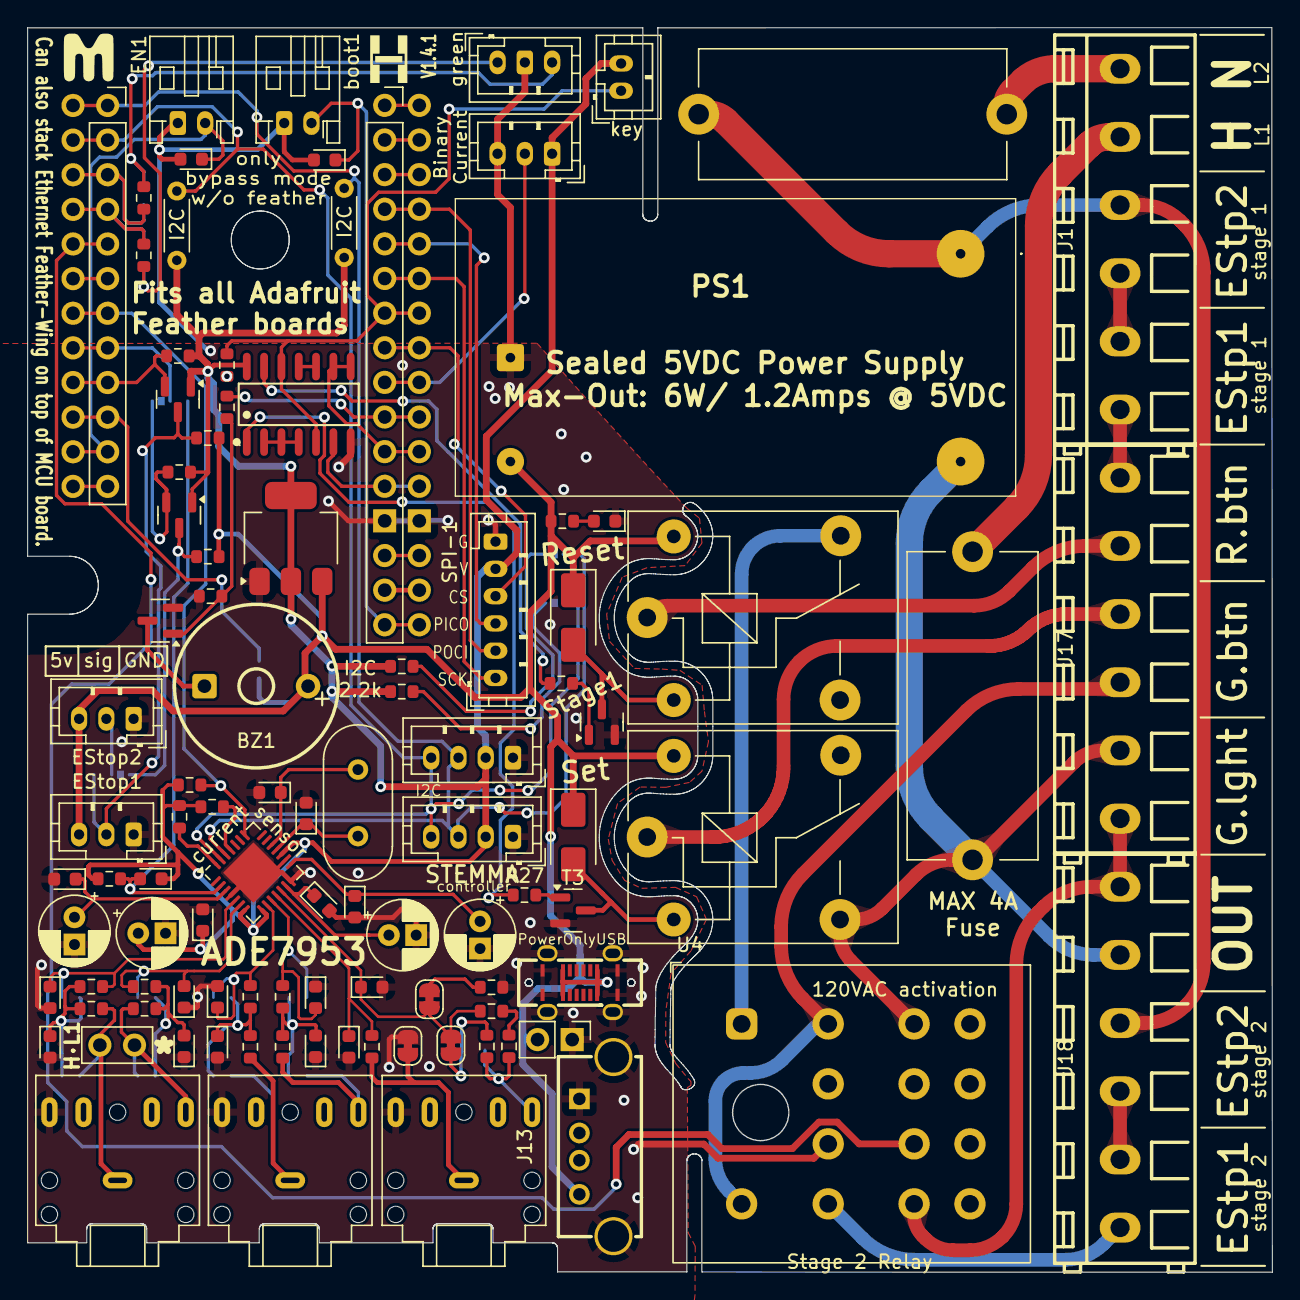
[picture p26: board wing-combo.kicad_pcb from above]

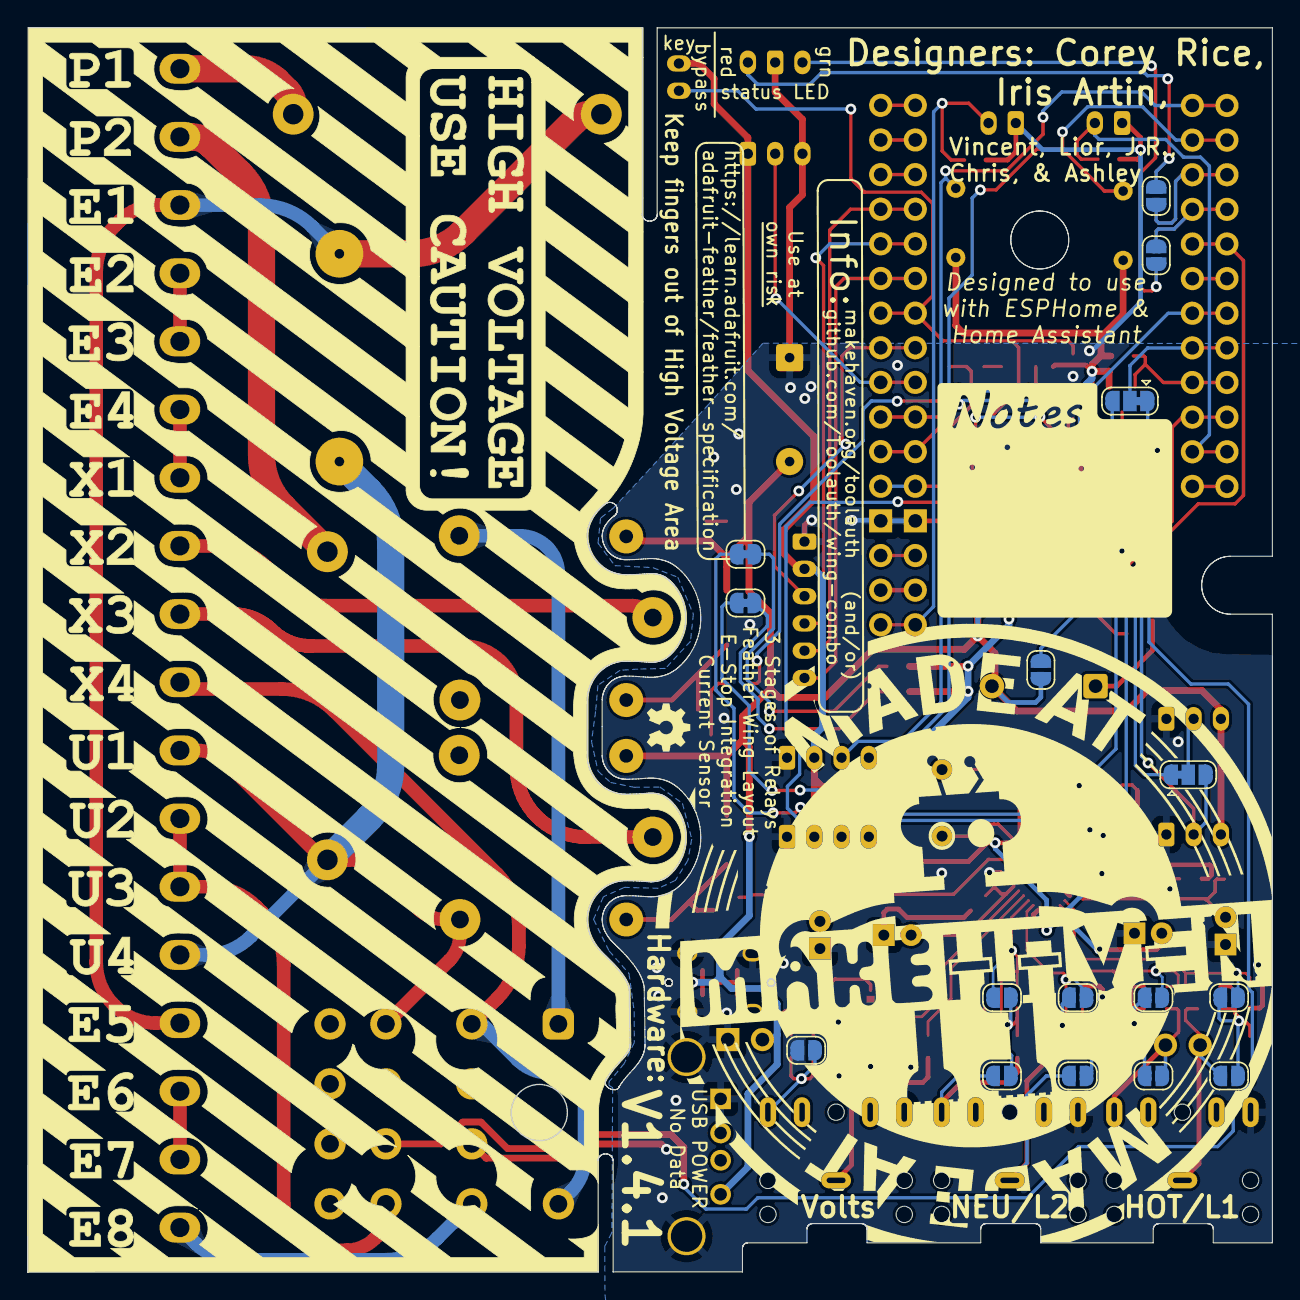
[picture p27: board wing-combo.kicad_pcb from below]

Board: 2 copper layers, 91.3 x 91.3 mm, 118 parts (16 on the bottom side), 89 nets.

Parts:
BZ1: Buzzer; BUZ-TH_BD12.0-P7.60-D0.6-FD
Bypass-1: Conn_01x02_Female; JST_PH_B2B-PH-K_1x02_P2.00mm_Vertical
C1, C2: 0.1uF; LED_0603_1608Metric
C3, C4, C5, C6, C7, C8, C9, C10, C11, C12: 33nF; LED_0603_1608Metric
C13, C16, C17, C22: 100nF; LED_0603_1608Metric
C14: 10uF; CP_Radial_D5.0mm_P2.00mm
C15: 1uF; LED_0603_1608Metric
C18, C19, C23: 4.7uF; CP_Radial_D5.0mm_P2.00mm
C20, C21: 20pF; LED_0603_1608Metric
D2: LED; LED_0603_1608Metric
D3, D4: SS14; D_SMA
EN1: Conn_01x02_Female; JST_PH_S2B-PH-K_1x02_P2.00mm_Horizontal
EStop1, EStop2: Conn_01x03_Female; JST_PH_B3B-PH-K_1x03_P2.00mm_Vertical
F1, F2: Fuse; Fuseholder_Cylinder-5x20mm_Stelvio-Kontek_PTF78_Horizontal_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
I2C-2: JST_PH_B4B-PH-K_1x04_P2.00mm_Vertical
I2C-3: Conn_01x04_Female; JST_PH_B4B-PH-K_1x04_P2.00mm_Vertical
IN-AUX-1: H/L1; PinHeader_1x02_P2.54mm_Vertical
J1, J17, J18: Screw_Terminal_01x06; CONN-TH_6P-P5.00_MX128-5.0-06P-GN01-CU-Y-A
J3, J4: Conn_01x12; PinSocket_1x12_P2.54mm_Vertical
J5: USB_C_Receptacle_USB2.0_16P; USB-C-TH_GT-USB-7055
J6: H/L1; Jack_3.5mm_CUI_SJ1-3525N_Horizontal
J7: N/L2; Jack_3.5mm_CUI_SJ1-3525N_Horizontal
J8: VOLTS; Jack_3.5mm_CUI_SJ1-3525N_Horizontal
J13: USB_A; USB-A-TH_USB-2.0-A-F-180-JCJ-H20.5
J15, J16: Conn_01x16; PinSocket_1x16_P2.54mm_Vertical
JP1, JP2, JP3, JP4, JP5, JP8, JP9, JP10, JP11, JP15, JP16, JP17: no-filter-1; SolderJumper-2_P1.3mm_Open_RoundedPad1.0x1.5mm
JP6, JP7, JP12, JP18, JP19: bridged; SolderJumper-2_P1.3mm_Bridged_RoundedPad1.0x1.5mm
JP13, JP14: SolderJumper_3_Bridged12; SolderJumper-3_P1.3mm_Bridged12_RoundedPad1.0x1.5mm
PS1: CFM06S050; CFM06S050E
R1, R5, R6, R14, R15, R16, R17, R18, R20, R21, R26, R27, R40: 1k; R_0603_1608Metric
R2, R3, R4, R22, R23, R24, R25, R28, R34, R35: 10k; R_0603_1608Metric
R7, R8: 2.2k; R_0603_1608Metric
R9, R10, R11, R12: 100; R_0603_1608Metric
R13, R19: 499k; R_0603_1608Metric
R32, R33: R_US; R_Axial_DIN0204_L3.6mm_D1.6mm_P5.08mm_Horizontal
R-G-LED1: Conn_01x03_Female; JST_PH_B3B-PH-K_1x03_P2.00mm_Vertical
SPI-1: Conn_01x06_Female; JST_PH_B6B-PH-K_1x06_P2.00mm_Vertical
T1, T2, T3, T4, T6: AO3400A; SOT-23
U1: 74HC02; SOIC-14_L8.7-W3.9-P1.27-LS6.0-BL
U2: ADE7953xCP; LFCSP-28-1EP_5x5mm_P0.5mm_EP3.14x3.14mm
U3: AMS1117-3.3; SOT-223-3_TabPin2
U4: PY14-02; Relay_Socket_4PDT_Omron_PY14-02-local
Y1: 3.58MHz; Crystal_HC49-4H_Vertical
binary-current1: Conn_01x03_Female; JST_PH_B3B-PH-K_1x03_P2.00mm_Vertical
boot1: Conn_01x02_Female; JST_PH_S2B-PH-K_1x02_P2.00mm_Horizontal
pwr5v1: extra; PinHeader_1x02_P2.54mm_Vertical
relay1, relay2: JQC-3FF/005-1ZS(551); Relay_SPDT_SANYOU_SRD_Series_Form_C

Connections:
+3.3V: Bypass-1.2, C13.1, C14.1, C15.1, I2C-2.2, I2C-3.2, R3.2, R7.2, R8.2, R22.2, R23.2, R24.2, R25.2, R32.1, R33.1, R34.2, SPI-1.5, T2.1 (G), T6.1 (G), U1.14 (VCC), U2.7 (PULL_HIGH), U2.8 (PULL_HIGH), U2.17 (VDD), U3.2 (VO), binary-current1.1
+3.3VA: J15.15, J16.15
+5V: BZ1.1 (+), D3.1 (K), D4.1 (K), EStop1.3, EStop2.3, J5.A4 (VBUS), J5.A9 (VBUS), J5.B4 (VBUS), J5.B9 (VBUS), J13.1 (VBUS), JP17.2 (B), PS1.3 (+VOUT), R4.2, R26.2, R35.2, U3.3 (VI), pwr5v1.2, relay1.5, relay2.5
/microcontroller/lightsounds/dcp1: BZ1.2 (-), T1.3 (D)
CS: R24.1, U2.28 (~CS)
CS-eth0: J3.6, J4.6
CS-jst: J15.8, J16.8, SPI-1.4
DC-read-stage2: J3.5, J4.5, U4.7 (sw3-no)
EN: C2.1, EN1.1, J3.11, J4.11
GND: C1.2, C2.2, C3.2, C4.1, C5.2, C6.1, C7.2, C8.1, C9.2, C10.1, C11.2, C12.2, C13.2, C14.2, C16.2, C17.2, C18.2, C19.2, C20.2, C21.2, C22.2, C23.2, D2.1 (K), EN1.2, EStop1.1, EStop2.1, I2C-2.1, I2C-3.1, J5.A1 (GND), J5.A12 (GND), J5.B1 (GND), J5.B12 (GND), J5.S1 (SHIELD), J6.R, J7.R, J8.R, J13.4 (GND), J13.5 (Shield), J13.6, J15.13, J16.13, JP1.1 (A), JP6.1 (A), PS1.4 (-VOUT), R2.1, R21.2, R28.1, R-G-LED1.2, SPI-1.6, T1.2 (S), T3.2 (S), T4.2 (S), U1.7 (GND), U2.4 (DGND), U2.14 (PULL_LOW), U2.16 (AGND), U2.29 (EP), U3.1 (GND), U4.11 (sw3-com), binary-current1.3, boot1.2, pwr5v1.1
Green-Indicator-light-1: F1.2, J17.2, J18.5, PS1.2 (ACL), U4.5 (sw1-no), relay1.3
Green-Indicator-light-2: J17.1, J18.6, U4.8 (sw4-no)
H/L1: F1.1, J1.5
IAN: C8.2, JP9.1 (A), R16.1, U2.6 (IAN)
IAN_IN: IN-AUX-1.2, J6.T, JP3.2 (B), R10.2
IAP: C7.1, JP8.2 (B), R15.2, U2.5 (IAP)
IAP_IN: IN-AUX-1.1, J6.S, JP2.1 (A), R9.1
IBN: C10.2, JP11.1 (A), R18.1, U2.10 (IBN)
IBN_IN: J7.T, JP5.2 (B), R12.2
IBP: C9.1, JP10.2 (B), R17.2, U2.9 (IBP)
IBP_IN: J7.S, JP4.1 (A), R11.1
Member-E-Stop-aux1-1: J18.2, J18.3
Member-E-Stop-aux2-1: J1.2, J1.3
Member-E-Stop-aux2-2: F2.2, J1.4, J18.4, PS1.1 (ACN)
Member-E-Stop-sw1-1: J18.1, U4.12 (sw4-com)
Member-E-Stop-sw2-1: J1.1, J17.6
Member-Green-Button-1: J17.4, relay1.1
Member-Green-Button-2: J17.3, U4.9 (sw1-com), U4.14 (solenoid)
Member-Red-Reset-Button-1: J17.5, relay2.1
unnamed: D2.2 (A), R26.1
unnamed: D3.2 (A), T3.3 (D), relay1.2
unnamed: D4.2 (A), T4.3 (D), relay2.2
unnamed: EStop1.2, JP14.3 (B), R4.1, T2.3 (D)
unnamed: EStop2.2, JP14.2 (C)
unnamed: J3.10, J4.10, JP17.1 (A)
unnamed: J3.12, J4.12
unnamed: J15.1, J16.1
unnamed: J15.2, J16.2
unnamed: J15.3, J16.3
unnamed: J15.14, J16.14
unnamed: C3.1, JP2.2 (B), JP8.1 (A), R9.2, R15.1
unnamed: C4.2, JP3.1 (A), JP9.2 (B), R10.1, R16.2
unnamed: JP7.1 (A), R14.1
unnamed: C5.1, JP4.2 (B), JP10.1 (A), R11.2, R17.1
unnamed: C6.2, JP5.1 (A), JP11.2 (B), R12.1, R18.2
unnamed: JP12.1 (A), R21.1
unnamed: C15.2, JP13.3 (B), R22.1, U2.2 (~RESET)
unnamed: JP14.1 (A), R35.1, T6.3 (D)
unnamed: JP15.2 (B), R5.2, R-G-LED1.3
unnamed: JP16.2 (B), R6.1, R-G-LED1.1
unnamed: JP18.2 (B), R8.1
unnamed: JP19.2 (B), R7.1
unnamed: R13.1, R19.2
unnamed: R27.1, U1.1
unnamed: R40.1, U1.13
unnamed: R1.2, R2.2, T1.1 (G)
unnamed: R27.2, T3.1 (G)
unnamed: R40.2, T4.1 (G)
unnamed: U1.2, U1.3, U1.4
unnamed: U1.10, U1.11
unnamed: C21.1, U2.18 (CLKIN), Y1.1
unnamed: C20.1, U2.19 (CLKOUT), Y1.2
unnamed: C22.1, C23.1, U2.13 (REF)
unnamed: C17.1, C19.1, U2.15 (VINTA)
unnamed: C16.1, C18.1, U2.3 (VINTD)
N/L2: F2.1, J1.6
PICO: J15.5, J16.5, SPI-1.3
POCI: J15.4, J16.4, SPI-1.2
SCK: J15.6, J16.6, SPI-1.1
SCL: I2C-2.4, I2C-3.4, J3.2, J4.2, JP18.1 (A), R33.2, U2.27 (MOSI/SCL/RX)
SCLK: R25.1, U2.25 (SCLK)
SDA: I2C-2.3, I2C-3.3, J3.1, J4.1, JP19.1 (A), R32.2, U2.26 (MISO/SDA/TX)
VN: C12.1, R20.1, U2.11 (VN)
VN_IN: J8.S, JP6.2 (B), R20.2
VP: C11.1, JP7.2 (B), JP12.2 (B), R19.1, U2.12 (VP)
VP_IN: J8.T, JP1.2 (B), R13.2, R14.2
ade7953-IRQ: J3.7, J4.7, R23.1, U2.22 (~IRQ)
binary-current: J15.9, J16.9, binary-current1.2
boot: C1.1, J15.16, J16.16, boot1.1
buzz: J15.10, J16.10, R1.1
led-grn: J3.4, J4.4, JP16.1 (A), R6.2
led-red: J3.3, J4.3, JP15.1 (A), R5.1
read-E-Stop: J3.9, J4.9, R3.1, T2.2 (S)
read-aux-E-Stop: JP13.1 (A), R34.1, T6.2 (S)
read-bypass: Bypass-1.1, J15.7, J16.7, R28.2, U1.5, U1.12
reset: U4.13 (solenoid), relay2.4
reset3v: J15.11, J16.11, U1.8, U1.9
set3v: J15.12, J16.12, U1.6
two-options: J3.8, J4.8, JP13.2 (C)

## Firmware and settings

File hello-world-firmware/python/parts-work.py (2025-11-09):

import time
import board
import digitalio
import busio
import pwmio
import wifi
import socketpool
import os
import adafruit_rtttl
import adafruit_ade7953
import adafruit_pn532.i2c
from adafruit_httpserver import Server, Request, Response, GET

print("Booting CircuitPython network-enabled test...")

# --- Pin Definitions (from YAML) ---
pin_sda = board.GP3
pin_scl = board.GP4
# pin_irq = board.GP11  # Not used by the ADE library
pin_red_led = board.GP5
pin_green_led = board.GP6
pin_reset_relay = board.GP17
pin_set_relay = board.GP18
pin_buzzer = board.GP16
pin_bypass_key = board.GP8
pin_estop_1 = board.GP13
pin_estop_2 = board.GP12
pin_bin_cur = board.GP15
pin_relay_feedback = board.GP9

# --- Connect to WiFi (from YAML) ---
try:
    print(f"Connecting to WiFi: {os.getenv('CIRCUITPY_WIFI_SSID')}")
    wifi.radio.connect(os.getenv("CIRCUITPY_WIFI_SSID"), os.getenv("CIRCUITPY_WIFI_PASSWORD"))
    print(f"IP Address: {wifi.radio.ipv4_address}")
    pool = socketpool.SocketPool(wifi.radio)
    server = Server(pool, debug=True)
except Exception as e:
    print(f"Failed to connect to WiFi or start server: {e}")
    # In a real app, you might start the AP fallback here.
    # For this test, we'll stop if WiFi fails.
    while True: pass 

# --- Initialize I2C and Peripherals ---
i2c = busio.I2C(pin_scl, pin_sda)

try:
    ade = adafruit_ade7953.ADE7953_I2C(i2c)
    print("ADE7953 Initialized.")
except Exception as e:
    print(f"Failed to init ADE7953: {e}")
    ade = None

try:
    pn532 = adafruit_pn532.i2c.PN532_I2C(i2c, debug=False)
    fw_version = pn532.firmware_version
    print(f"Found PN532! Firmware ver. {fw_version[0]}.{fw_version[1]}")
except Exception as e:
    print(f"Failed to init PN532: {e}")
    pn532 = None
    
# --- Initialize Buzzer ---
buzzer = pwmio.PWMOut(pin_buzzer, frequency=440, duty_cycle=0, variable_frequency=True)
mario_song = "mario:d=4,o=5,b=100:16e6,16e6,32p,8e6,16c6,8e6,8g6,8p,8g,8p,8c6,16p,8g,16p,8e,16p,8a,8b,16a#,8a,16g.,16e6,16g6,8a6,16f6,8g6,8e6,16c6,16d6,8b,16p,8c6,16p,8g,16p,8e,16p,8a,8b,16a#,8a,16g.,16e6,16g6,8a6,16f6,8g6,8e6,16c6,16d6,8b,8p,16g6,16f#6,16f6,16d#6,16p,16e6,16p,16g#,16a,16c6,16p,16a,16c6,16d6,8p,16g6,16f#6,16f6,16d#6,16p,16e6,16p,16c7,16p,16c7,16c7,p,16g6,16f#6,16f6,16d#6,16p,16e6,16p,16g#,16a,16c6,16p,16a,16c6,16d6,8p,16d#6,8p,16d6,8p,16c6"

# --- Initialize Outputs ---
outputs = {
    "red": digitalio.DigitalInOut(pin_red_led),
    "green": digitalio.DigitalInOut(pin_green_led),
    "set": digitalio.DigitalInOut(pin_set_relay),
    "reset": digitalio.DigitalInOut(pin_reset_relay)
}
for out in outputs.values():
    out.direction = digitalio.Direction.OUTPUT

# --- Initialize Inputs (Matching YAML) ---
inputs = {
    "bypass_key": digitalio.DigitalInOut(pin_bypass_key),
    "estop_1": digitalio.DigitalInOut(pin_estop_1),
    "estop_2": digitalio.DigitalInOut(pin_estop_2),
    "bin_cur": digitalio.DigitalInOut(pin_bin_cur),
    "relay_feedback": digitalio.DigitalInOut(pin_relay_feedback)
}
for name, in_pin in inputs.items():
    in_pin.direction = digitalio.Direction.INPUT
    if name == "relay_feedback":
        in_pin.pull = digitalio.Pull.UP # Set pullup per YAML

# --- Web Server Routes ---

@server.route("/", GET)
def handle_root(request: Request):
    html = """<html><body><h1>Wing Combo IO Test (CircuitPython)</h1>
    <p><a href='/sensors'>Get Sensor JSON</a></p>
    <h2>Outputs</h2>
    <p>LEDs: <a href='/output/red/on'>Red ON</a> | <a href='/output/red/off'>Red OFF</a> | <a href='/output/green/on'>Green ON</a> | <a href='/output/green/off'>Green OFF</a></p>
    <p>Relays: <a href='/output/set/on'>Set ON</a> | <a href='/output/set/off'>Set OFF</a> | <a href='/output/reset/on'>Reset ON</a> | <a href='/output/reset/off'>Reset OFF</a></p>
    <h2>Actions</h2>
    <p><a href='/nfc'>Scan NFC Tag (blocking)</a></p>
    <p><a href='/playmario'>Play Mario Song (blocking)</a></p>
    </body></html>"""
    return Response(request, html, content_type="text/html")

@server.route("/sensors", GET)
def handle_sensors(request: Request):
    data = {}
    
    # Read binary sensors (All Active-LOW per YAML)
    for name, pin in inputs.items():
        data[name] = not pin.value # "not" provides the inverted logic
        
    # Read ADE7953
    if ade:
        try:
            data["ade7953"] = {
                "voltage": ade.voltage_rms,
                "current_a": ade.current_a,
                "current_b": ade.current_b,
                "active_power_a": ade.active_power_a,
                "active_power_b": ade.active_power_b
            }
        except Exception as e:
            data["ade7953"] = f"Error reading: {e}"
    else:
        data["ade7953"] = "Not initialized"
        
    return Response(request, str(data), content_type="application/json")

@server.route("/nfc", GET)
def handle_nfc(request: Request):
    if not pn532:
        return Response(request, "NFC Reader not initialized", status=500)
    
    msg = "NFC Scan: "
    try:
        uid = pn532.read_passive_target(timeout=0.1)
        if uid:
            msg += f"Tag found! UID: {[hex(i) for i in uid]}"
        else:
            msg += "No tag found."
    except Exception as e:
        msg += f"Error: {e}"
    return Response(request, msg, content_type="text/plain")

@server.route("/playmario", GET)
def handle_play_mario(request: Request):
    print("Playing Mario... (This will block other requests)")
    adafruit_rtttl.play(buzzer, mario_song)
    print("Done playing.")
    return Response(request, "Played Mario song.", content_type="text/plain")

@server.route("/output/<target>/<state>", GET)
def handle_output(request: Request, target: str, state: str):
    if target in outputs:
        outputs[target].value = (state == "on")
        # Redirect back to the root page
        return Response(request, "", headers={"Location": "/"})
    else:
        return Response(request, "Not Found", status=404)

# --- Start Server and Main Loop ---
print("Starting web server...")
server.start(str(wifi.radio.ipv4_address))

while True:
    try:
        # This single call handles all incoming requests
        server.poll()
    except Exception as e:
        print(f"Error in server loop: {e}")

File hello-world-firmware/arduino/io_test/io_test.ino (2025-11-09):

#include <WiFi.h>
#include <WebServer.h>
#include <ArduinoOTA.h>
#include <Wire.h>
#include <ADE7953_I2C.h> // For Energy Monitor
#include <Rtttl.h>        // For Buzzer
#include <Adafruit_PN532.h> // For NFC

// --- WiFi Credentials (from YAML) ---
const char* ssid = "your_wifi_ssid";
const char* password = "your_wifi_password";
const char* ota_password = "d3281c2e8ad00b965c8bbb69717ce993";

// --- Pin Definitions (from YAML) ---
#define PIN_SDA 3
#define PIN_SCL 4
#define PIN_IRQ 11 // For ADE7953
#define PIN_RED_LED 5
#define PIN_GREEN_LED 6
#define PIN_RESET_RELAY 17
#define PIN_SET_RELAY 18
#define PIN_BUZZER 16
#define PIN_BYPASS_KEY 8
#define PIN_ESTOP_1 13
#define PIN_ESTOP_2 12
#define PIN_BIN_CUR 15
#define PIN_RELAY_FEEDBACK 9
// Note: PN532 I2C doesn't need extra pins beyond I2C

// --- Global Objects ---
WebServer server(80);
ADE7953 myADE7953(PIN_SCL, PIN_SDA); // Note: Uses custom I2C pins
Adafruit_PN532 nfc(PIN_SDA, PIN_SCL); // Uses default I2C pins
FLASH_STRING(song, "mario:d=4,o=5,b=100:16e6,16e6,32p,8e6,16c6,8e6,8g6,8p,8g,8p,8c6,16p,8g,16p,8e,16p,8a,8b,16a#,8a,16g.,16e6,16g6,8a6,16f6,8g6,8e6,16c6,16d6,8b,16p,8c6,16p,8g,16p,8e,16p,8a,8b,16a#,8a,16g.,16e6,16g6,8a6,16f6,8g6,8e6,16c6,16d6,8b,8p,16g6,16f#6,16f6,16d#6,16p,16e6,16p,16g#,16a,16c6,16p,16a,16c6,16d6,8p,16g6,16f#6,16f6,16d#6,16p,16e6,16p,16c7,16p,16c7,16c7,p,16g6,16f#6,16f6,16d#6,16p,16e6,16p,16g#,16a,16c6,16p,16a,16c6,16d6,8p,16d#6,8p,16d6,8p,16c6");

// --- Webpage Handlers ---
void handleRoot() {
  String html = "<html><body><h1>Wing Combo IO Test (Arduino)</h1>";
  html += "<p><a href='/sensors'>Get Sensor JSON</a></p>";
  html += "<h2>Outputs</h2>";
  html += "<p>LEDs: <a href='/led/red/on'>Red ON</a> | <a href='/led/red/off'>Red OFF</a> | <a href='/led/green/on'>Green ON</a> | <a href='/led/green/off'>Green OFF</a></p>";
  html += "<p>Relays: <a href='/relay/set/on'>Set ON</a> | <a href='/relay/set/off'>Set OFF</a> | <a href='/relay/reset/on'>Reset ON</a> | <a href='/relay/reset/off'>Reset OFF</a></p>";
  html += "<h2>Actions</h2>";
  html += "<p><a href='/nfc'>Scan NFC Tag (blocking)</a></p>";
  html += "<p><a href='/playmario'>Play Mario Song (blocking)</a></p>";
  html += "</body></html>";
  server.send(200, "text/html", html);
}

void handleSensors() {
  // Read all sensors and format as JSON
  String json = "{";
  
  // Binary Sensors (All Active-LOW per YAML)
  json += "\"bypass_key\": " + String(!digitalRead(PIN_BYPASS_KEY));
  json += ", \"estop_1\": " + String(!digitalRead(PIN_ESTOP_1));
  json += ", \"estop_2\": " + String(!digitalRead(PIN_ESTOP_2));
  json += ", \"bin_cur\": " + String(!digitalRead(PIN_BIN_CUR));
  json += ", \"relay_feedback\": " + String(!digitalRead(PIN_RELAY_FEEDBACK));
  
  // ADE7953 Sensors
  json += ", \"ade7953\": {";
  json += "\"voltage\": " + String(myADE7953.getVrms()); // getVrms(), getIrmsA(), etc.
  json += ", \"current_a\": " + String(myADE7953.getIrmsA());
  json += ", \"current_b\": " + String(myADE7953.getIrmsB());
  json += ", \"active_power_a\": " + String(myADE7953.getActivePowerA());
  json += "}";
  
  json += "}";
  server.send(200, "application/json", json);
}

void handleNFC() {
  String msg = "NFC Scan: ";
  uint8_t success;
  uint8_t uid[] = { 0, 0, 0, 0, 0, 0, 0 };
  uint8_t uidLength;

  success = nfc.readPassiveTargetID(PN532_MIFARE_ISO14443A, uid, &uidLength, 100); // 100ms timeout

  if (success) {
    msg += "Tag found! UID: ";
    for (uint8_t i = 0; i < uidLength; i++) {
      msg += String(uid[i], HEX);
      msg += " ";
    }
  } else {
    msg += "No tag found.";
  }
  server.send(200, "text/plain", msg);
}

void handlePlayMario() {
  server.send(200, "text/plain", "Playing Mario...");
  Rtttl::play(song);
}

void handleOutput() {
  // Handle /led/red/on, /relay/set/off, etc.
  String target = server.pathArg(0);
  String state = server.pathArg(1);
  int pin = -1;
  
  if (target == "red") pin = PIN_RED_LED;
  if (target == "green") pin = PIN_GREEN_LED;
  if (target == "set") pin = PIN_SET_RELAY;
  if (target == "reset") pin = PIN_RESET_RELAY;
  
  if (pin != -1) {
    digitalWrite(pin, (state == "on") ? HIGH : LOW);
    handleRoot(); // Send back to main page
  } else {
    server.send(404, "text/plain", "Not Found");
  }
}

void setup() {
  Serial.begin(115200);
  Serial.println("Booting network-enabled test...");

  // --- Initialize Outputs ---
  pinMode(PIN_RED_LED, OUTPUT);
  pinMode(PIN_GREEN_LED, OUTPUT);
  pinMode(PIN_RESET_RELAY, OUTPUT);
  pinMode(PIN_SET_RELAY, OUTPUT);

  // --- Initialize Inputs (Matching YAML) ---
  // All are Active-LOW. pullup only on relay_feedback.
  pinMode(PIN_BYPASS_KEY, INPUT);
  pinMode(PIN_ESTOP_1, INPUT);
  pinMode(PIN_ESTOP_2, INPUT);
  pinMode(PIN_BIN_CUR, INPUT);
  pinMode(PIN_RELAY_FEEDBACK, INPUT_PULLUP);

  // --- Initialize I2C and Peripherals ---
  // Wire.begin(PIN_SDA, PIN_SCL); // Standard I2C init
  myADE7953.initialize(); // ADE library handles its own I2C
  nfc.begin();
  
  uint32_t versiondata = nfc.getFirmwareVersion();
  if (!versiondata) {
    Serial.println("Didn't find PN532 board");
  } else {
    Serial.print("Found PN532! Firmware ver. "); 
    Serial.print((versiondata >> 24) & 0xFF, HEX);
    Serial.print("."); 
    Serial.println((versiondata >> 16) & 0xFF, HEX);
  }

  // --- Connect to WiFi ---
  WiFi.mode(WIFI_STA);
  WiFi.begin(ssid, password);
  while (WiFi.status() != WL_CONNECTED) {
    delay(500);
    Serial.print(".");
  }
  Serial.println("\nWiFi connected. IP: " + WiFi.localIP().toString());

  // --- Setup Web Server Routes ---
  server.on("/", handleRoot);
  server.on("/sensors", handleSensors);
  server.on("/nfc", handleNFC);
  server.on("/playmario", handlePlayMario);
  // Route for /led/red/on, /relay/set/off, etc.
  server.on("/(led|relay)/(red|green|set|reset)/(on|off)", handleOutput);
  
  server.begin();

  // --- Setup OTA (matches YAML) ---
  ArduinoOTA.setHostname("wing-combo-io-test");
  ArduinoOTA.setPassword(ota_password);
  ArduinoOTA.begin();

  Serial.println("Ready. Visit IP address in browser.");
}

void loop() {
  ArduinoOTA.handle();   // Handle OTA requests
  server.handleClient(); // Handle web requests
  Rtttl::updateMelody(); // Update non-blocking RTTTL player
}

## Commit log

2024-03-07 remove reader ~ in a different project
    [reader-daughter-BOM.csv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]
2024-03-07 move board into main repo
    [CFM06S050-E.stp, ade7953.kicad_sch, breakoutbaords.kicad_sch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]
2024-03-07 remove reader-daughter (has its own repo now)
    [reader-daughter-BOM.csv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]
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2024-05-31 double-check mains connections, update notes
    [ade7953.kicad_sch, breakoutbaords.kicad_sch, esp32core.kicad_sch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]
2024-08-02 change URL on board to makehaven.org/toolauth, to match with Project name on GitHub
    [wing-combo.kicad_pcb]
2024-08-02 unpopulate headers that are not needed
    [ade7953.kicad_sch, breakoutbaords.kicad_sch, lightsounds.kicad_sch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]
2024-11-17 added candidate changes to accomodate Adafruit Ethernet feather-wing
    [ade7953.kicad_sch, breakoutbaords.kicad_sch, esp32core.kicad_sch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]
2024-11-28 add j151 relay documentation
    [J1512CP120VAC1.2.stp]
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2024-11-29 fixed j151 relay footprint...probably. also ordered physical relays to confirm
    [stage2relay.kicad_sch]
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2024-12-03 convert to new parts on the board: footprint change for relay and wishlist-JST connectors
    [lightsounds.kicad_sch, stage2relay.kicad_sch, wing-combo.kicad_pcb]
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2024-12-06 placed new screw terminals on board
    [stage3contactor.kicad_sch, wing-combo.kicad_pcb]
2024-12-06 flipped arbitrary pin-numberrs on relay, for better routing
    [wing-combo.kicad_pcb]
2024-12-06 save lcsc part number
    [stage3contactor.kicad_sch]
2024-12-10 candidate reconfiguration for bypass key operation and sensing
    [stage1relays.kicad_sch]
2024-12-10 reassigned netclasses, removed vestigial level-shifter
    [breakoutbaords.kicad_sch, lightsounds.kicad_sch, stage1relays.kicad_sch]
2024-12-10 flip pins on bypass key for better wire-routing
    [stage1relays.kicad_sch]
2024-12-10 [fix] bypass key and high-voltage routing
    [wing-combo.kicad_pcb]
2024-12-10 [fix] read-bypass link
    [breakoutbaords.kicad_sch, wing-combo.kicad_pcb]
2024-12-10 [new] assigned CS pin for JST-SPI and Ethernet Feather-Wing
    [breakoutbaords.kicad_sch, wing-combo.kicad_pcb]
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2024-12-10 added more parts from EasyEDA with the easyeda2kicad script
    [CFM06S050-E.stp, J1512CP120VAC1.2.stp]
2024-12-10 added 3D models to design
    [lightsoundbuttons.kicad_sch, lightsounds.kicad_sch, mainslevelcontrol.kicad_sch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]
2024-12-11 [fix] PICO/POCI flipped on Feather Boards
    [breakoutbaords.kicad_sch, esp32core.kicad_sch, wing-combo.kicad_pcb]
2024-12-11 added USBC, much to Vincent's delight :)
    [USB-C-SMD_GT-USB-7002C.step]
2024-12-11 added USBC for power. Changed Feather power-supply to be incompliance with Feather's recommendations
    [breakoutbaords.kicad_sch, esp32core.kicad_sch, wing-combo.kicad_pcb]
2024-12-11 added lcsc_id
    [breakoutbaords.kicad_sch]
2024-12-12 fix USBC-vertical footprint drill holes
2024-12-12 bugfixes galore!
    [lightsounds.kicad_sch, wing-combo.kicad_pcb]
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2024-12-13 add 3D model of ADE7953
    [wing-combo.kicad_pcb]
2024-12-24 improved F.silkscreen for before hand-soldering
    [wing-combo.kicad_pcb]
2025-01-06 moved LED GPIO to fit free pins for ethernet wing
    [ade7953.kicad_sch, breakoutbaords.kicad_sch, microcontroller.kicad_sch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]
2025-01-22 working through DRC checks
    [breakoutbaords.kicad_sch, wing-combo.kicad_pcb]
2025-01-23 usbc schematic/footprint aligned
    [wing-combo.kicad_pcb]
2025-02-05 ordered B1P3 test run from JLCPCB
    [ade7953.kicad_sch, breakoutbaords.kicad_sch, lightsounds.kicad_sch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]
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2025-02-17 bypass key disables reset relay. Based on recommendation from Lior
    [stage1relays.kicad_sch, wing-combo.kicad_pcb]
2025-02-25 added 74HC02 to stage 1 relay schematic
    [stage1relays.kicad_sch]
2025-02-25 update text
    [stage1relays.kicad_sch]
2025-07-04 parts for bypass XOR
    [RES-ARRAY-SMD_0402-8P-L2.0-W1.0-BL.step, RES-ARRAY-SMD_0603-8P-L3.2-W1.6-BL.step, SOIC-14_L8.7-W3.9-P1.27-LS6.0-BL.step]
2025-07-04 rename misspelled file
    [breakoutboards.kicad_sch, microcontroller.kicad_sch]
2025-07-04 changed to py14-02 relay socket
    [stage2relay.kicad_sch, wing-combo.kicad_pcb]
2025-07-04 local variant of PY14-02 footprint
    [stage2relay.kicad_sch]
2025-07-04 [auto] annotate schematic
    [ade7953.kicad_sch]
2025-09-21 1.4.1 schematic update
    [ade7953.kicad_sch, breakoutboards.kicad_sch, esp32core.kicad_sch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]
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2025-09-21 3d model for relay socket
    [PY14_02.step]
2025-09-21 partway progress
    [wing-combo.kicad_pcb]
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2025-09-21 handled DRC errors on board design
    [wing-combo.kicad_pcb]
2025-09-22 update jumper numbers
    [ade7953.kicad_sch]
2025-09-22 update jumper numbers pt2
    [ade7953.kicad_sch]
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2025-09-22 PCB update
    [wing-combo.kicad_pcb]
2025-09-22 remove unused parts
    [J1512CP120VAC1.2.stp]
2025-09-22 relocate PY14 socker step file
    [PY14_02.step, wing-combo.kicad_pcb]
2025-09-22 baord versioning on silkscreen
    [wing-combo.kicad_pcb]
2025-09-23 update traces on USB-A
    [wing-combo.kicad_pcb]
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2025-09-26 update reference values for better ibom
    [ade7953.kicad_sch, breakoutboards.kicad_sch, lightsounds.kicad_sch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]
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2025-10-05 before new branch
    [breakoutboards.kicad_sch]
2025-10-09 nearly ready
    [F1812.step, SOIC-8_L5.0-W4.0-P1.27-LS6.0-BL.step, breakoutboards.kicad_sch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]
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2025-10-15 5v binary current and cleanup
    [ade7953.kicad_sch, breakoutboards.kicad_sch, esp32core.kicad_sch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]
2025-10-25 close enough for 3D export
    [ade7953.kicad_sch, breakoutboards.kicad_sch, esp32core.kicad_sch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]
2025-11-02 commit production files
    [bom.csv, positions.csv]
2025-11-03 merged shift-bin-cur
    [F1812.step, PY14_02.step, RES-ARRAY-SMD_0402-8P-L2.0-W1.0-BL.step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]
2025-11-03 rename and cleanup
    [RES-ARRAY-SMD_0402-8P-L2.0-W1.0-BL.step, RES-ARRAY-SMD_0603-8P-L3.2-W1.6-BL.step]
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2025-11-03 moved to kicad 9
    [ade7953.kicad_sch, breakoutboards.kicad_sch, esp32core.kicad_sch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]
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2025-11-04 nearly ready for v1.4.4
    [Toolauth_Wing-Combo_1.4.4_bom.csv, Toolauth_Wing-Combo_1.4.4_positions.csv]
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
